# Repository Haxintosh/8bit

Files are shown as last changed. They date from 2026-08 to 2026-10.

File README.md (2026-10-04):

# 8bit
8-bit SAP-3 inspired architecture using 74xx series logic chips.

## Files
KiCad design files can be found under `schematic/`, clone and open `8bit.kicad_pro`.  
Schematic PDF is under `schematic/pdf/`.  
Simulation files for Digital can be found under `simulation/`.  
Open the `main_manual.dig` in Digital to view the simulation.  
Some of the hex files to program EEPROMs are under `simulation/hex/`.  

## Features
- 8 bit wide data bus
- 16 bit wide address bus
- 8 bit A/B/C/D/E/H/L/temporary registers
- BC, DE, HL can pair up to become a 16 bit wide register
- 32k RAM
- Memory-Mapped IO
- 16 bit stack pointer, memory address register, program counter
- 8080-like instruction set
- CompactFlash read/write
- LCD output

## Demo
1.  (Video) A simplified SAP-1 version running fibonacci sequence code.
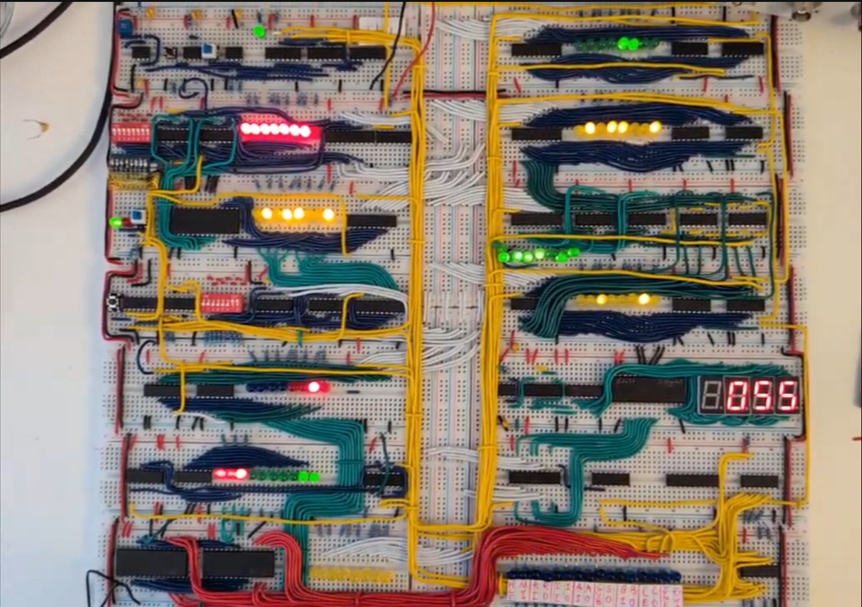
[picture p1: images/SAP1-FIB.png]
SAP-1 version running fibonacci sequence code (https://drive.google.com/file/d/1dBzOrb9bEsT9MGzf2OnXLOOiJT2EtECz/view?usp=sharing)


2. SAP-3 in simulation
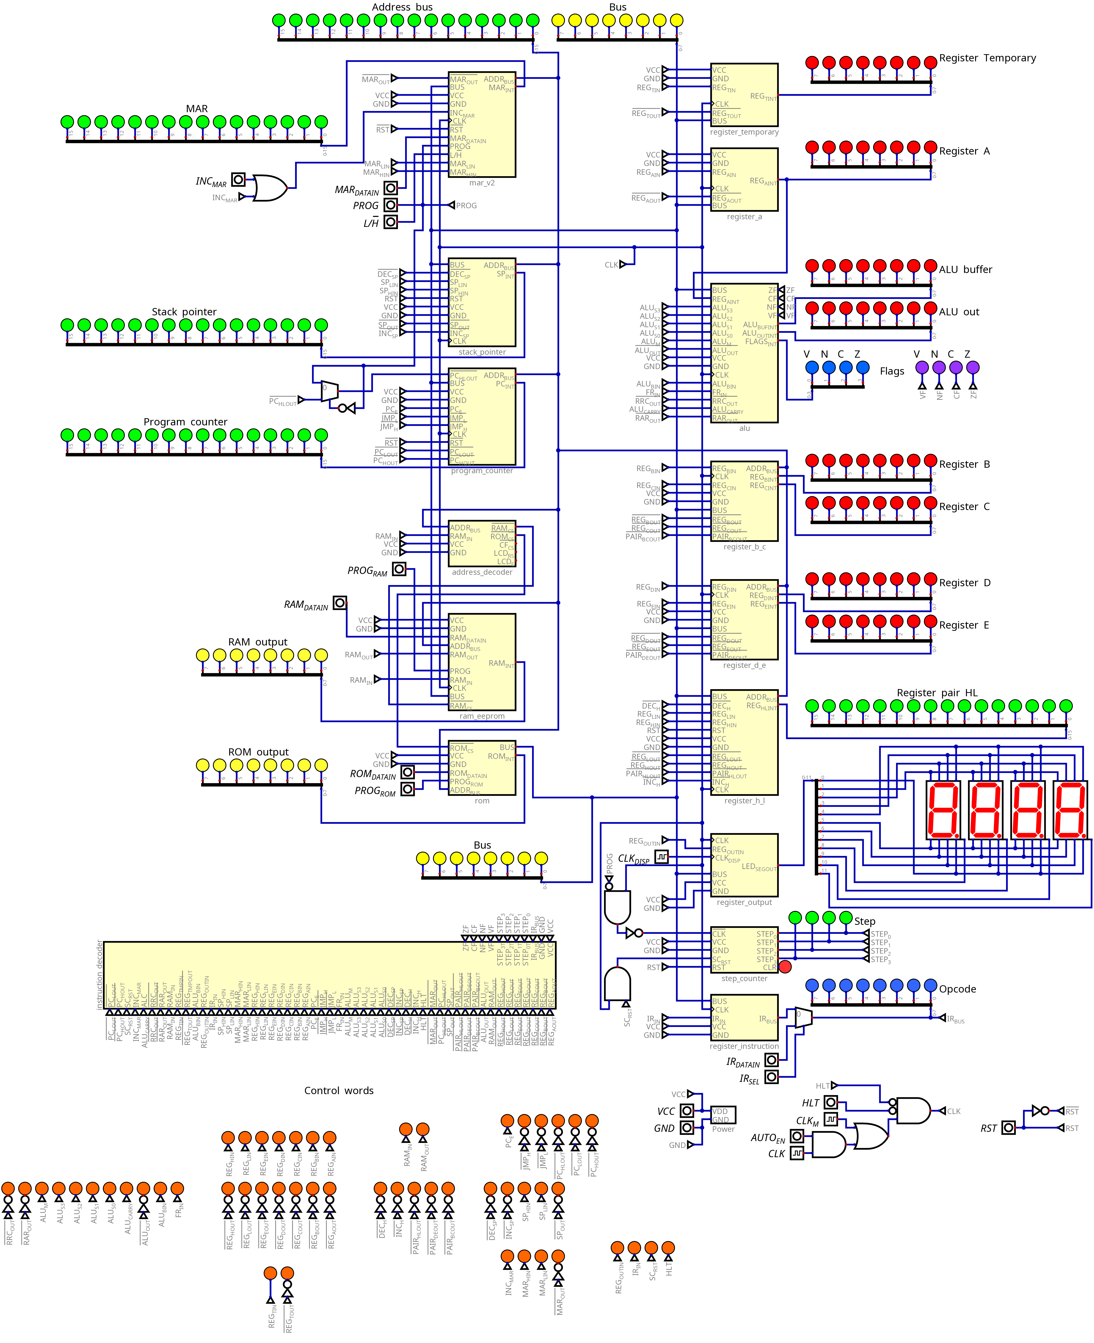
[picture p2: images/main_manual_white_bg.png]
SAP-3 digital simulation


3. (Video) SAP-3 running fibonacci code
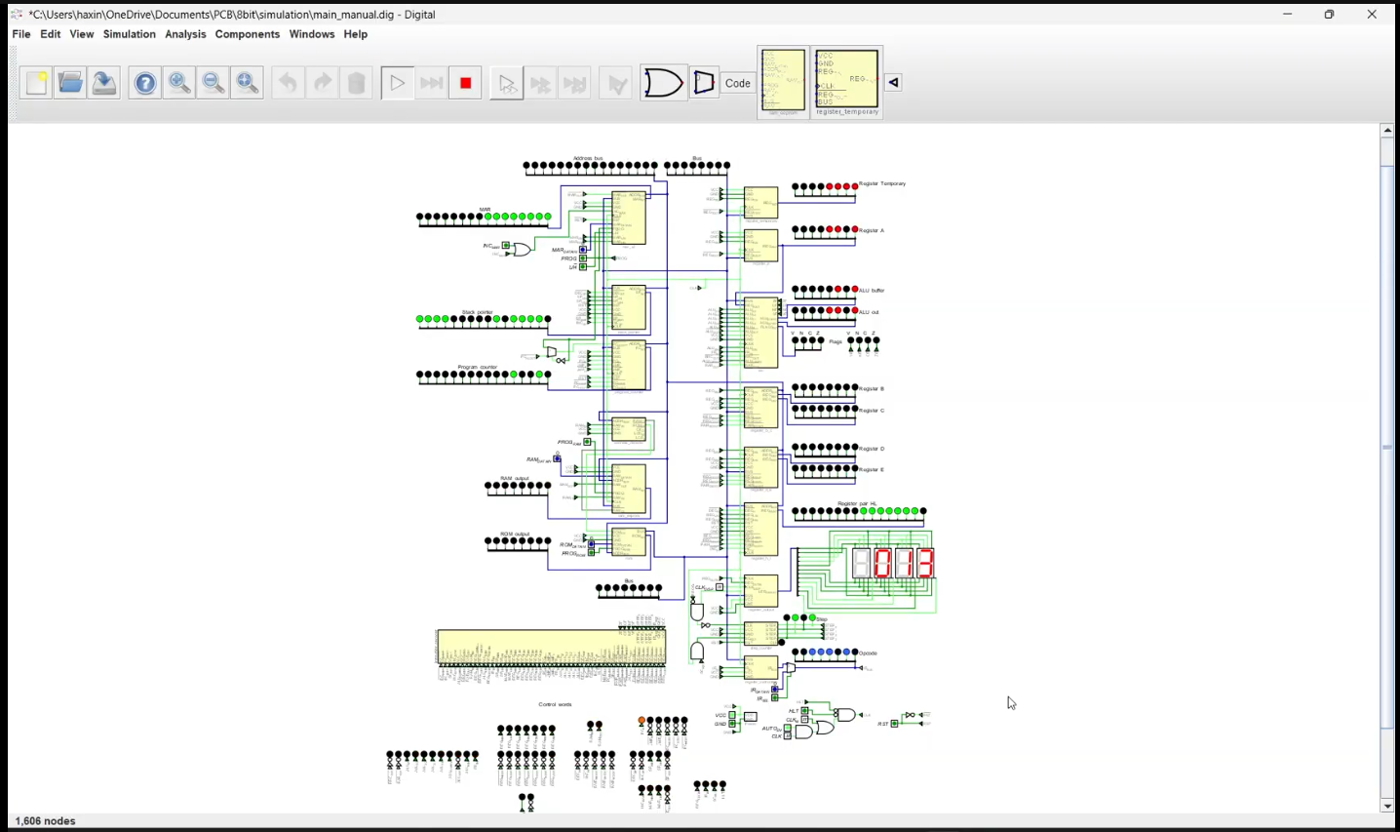
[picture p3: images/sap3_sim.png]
SAP-3 running fibonacci sequence code (https://drive.google.com/file/d/1ePPz25QHvrzXUbd5AwPUnTJGdm06tiAX/view?usp=sharing)


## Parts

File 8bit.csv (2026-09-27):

Reference | Qty | Value | DNP | Exclude from BOM | Exclude from Board | Footprint | Datasheet
C1,C2,C3,C5 | 4 | 0.01uF
C4 | 1 | 0.1uF
D17,D18,D19,D20,D21,D22,D23,D24,D25,D26,D27,D28,D29,D30,D31,D32,D33,D34,D35,D36,D37,D38,D39,D40,D41,D42,D43,D44,D45,D46,D47,D48,D49,D50,D51,D52,D53,D54,D55,D56,D57,D58,D59,D60,D61,D62,D63,D64,D65,D66,D67,D68,D69,D70,D71,D72,D73,D74,D75,D76,D77,D78,D79,D80,D81,D82,D83,D84,D85,D86,D87,D88,D89,D90,D91,D92,D93,D94,D95,D96,D97,D98,D99,D100,D101,D102,D103,D104,D105,D106,D107,D108,D109,D110,D111,D112,D113,D114,D115,D116,D117,D118,D119,D120,D121,D122,D123,D124,D125,D126,D127,D128,D129,D130,D131,D132,D133,D134,D135,D136,D137,D138,D139,D140,D141,D142,D143,D144,D145,D146,D147,D148,D149,D150,D151,D152,D153,D154,D155,D156,D157,D158,D159,D160,D161,D162,D163,D164,D165,D166,D167,D168,D169,D170,D171,D172,D173,D174,D175,D176,D177,D178,D179,D180,D181,D182,D183,D184,D185,D186,D187,D188,D189,D190,D191,D192,D193,D194,D195,D196,D197 | 181 | LED |  |  |  | LED_SMD:LED_0805_2012Metric
DS1 | 1 | WC1602A |  |  |  | Display:WC1602A | http://www.wincomlcd.com/pdf/WC1602A-SFYLYHTC06.pdf
J1 | 1 | CF |  |  |  | easyeda2kicad:CONN-SMD_HYCW01-CF50-395B
J2 | 1 | EXTR
JP1 | 1 | Master
R17,R18,R19,R20,R21,R22,R23,R24,R25,R26,R27,R28,R29,R30,R31,R32,R33,R34,R35,R36,R37,R38,R39,R40,R41,R42,R43,R44,R45,R46,R47,R48,R49,R50,R51,R52,R53,R54,R55,R56,R57,R58,R59,R60,R61,R62,R63,R64,R65,R66,R67,R68,R70,R72,R74,R76,R78,R80,R82,R84,R86,R88,R90,R92,R94,R96,R98,R100,R101,R102,R103,R104,R105,R106,R107,R108,R109,R110,R111,R112,R113,R114,R115,R116,R117,R118,R119,R120,R121,R122,R123,R124,R125,R126,R127,R128,R129,R130,R131,R132,R133,R134,R135,R136,R137,R138,R139,R140,R145,R146,R147,R148,R149,R150,R151,R152,R153,R154,R155,R156,R157,R158,R159,R160,R161,R162,R163,R164,R165,R166,R167,R168,R169,R170,R171,R172,R173,R174,R175,R176,R177,R178,R179,R180,R181,R182,R183,R184,R185,R186,R187,R188,R189,R190,R191,R192,R193,R194,R195,R196,R201,R204,R205,R206,R209,R210,R211,R212,R213,R214,R215,R216,R217,R218,R219,R220,R221,R222,R223,R224,R225 | 181 | 470 |  |  |  | Resistor_SMD:R_0805_2012Metric
R69,R71,R73,R75,R77,R79,R81,R83,R85,R87,R89,R91,R93,R95,R97,R99,R232,R233,R234,R235,R236,R237,R238,R239,R240,R241,R242,R243,R244,R245,R246,R247 | 32 | 1k |  |  |  | Resistor_SMD:R_0805_2012Metric
R141,R142 | 2 | R
R143 | 1 | 1M
R144,R207,R208 | 3 | 1k
R197,R198,R199,R200,R202 | 5 | 0 |  |  |  | Resistor_SMD:R_0805_2012Metric
R203 | 1 | 4.7k |  |  |  | Resistor_SMD:R_0805_2012Metric
RV1 | 1 | 10k
SW1 | 1 | RST
SW2 | 1 | SW_Push
SW3 | 1 | SW_SPDT
SW4,SW5 | 2 | SW_DIP_x08
U1,U81 | 2 | 74LS04 |  |  |  |  | http://www.ti.com/lit/gpn/sn74LS04
U2,U3,U82,U95 | 4 | 74LS08 |  |  |  |  | http://www.ti.com/lit/gpn/sn74LS08
U3,U83 | 2 | 74LS32 |  |  |  |  | http://www.ti.com/lit/gpn/sn74LS32
U4 | 1 | 74LS02 |  |  |  |  | http://www.ti.com/lit/gpn/sn74ls02
U5,U6,U7,U8,U61,U84,U85,U86,U87 | 9 | 74LS161 |  |  |  | Package_DIP:DIP-16_W7.62mm_Socket | http://www.ti.com/lit/gpn/sn74LS161
U9,U10,U15,U16,U20,U21,U23,U25,U30,U31,U37,U39,U40,U41,U44,U45,U46,U47,U50,U51,U52,U53,U70,U88,U89,U93,U94 | 27 | 74LS245 |  |  |  | Package_DIP:DIP-20_W7.62mm_Socket | http://www.ti.com/lit/gpn/sn74LS245
U11,U12,U13,U14,U26,U27,U48,U49 | 8 | 74LS193 |  |  |  | Package_DIP:DIP-16_W7.62mm_Socket | http://www.ti.com/lit/ds/symlink/sn74ls193.pdf
U17 | 1 | 74LS138 |  |  |  | Package_DIP:DIP-16_W7.62mm_Socket | http://www.ti.com/lit/gpn/sn74LS138
U18 | 1 | 74LS20 |  |  |  | Package_DIP:DIP-14_W7.62mm_Socket | http://www.ti.com/lit/gpn/sn74LS20
U19 | 1 | HM62256BLP |  |  |  | Package_DIP:DIP-28_W15.24mm_Socket | https://web.mit.edu/6.115/www/document/62256.pdf
U22 | 1 | KM28C64A |  |  |  | Package_DIP:DIP-28_W15.24mm_Socket | https://tvsat.com.pl/PDF/K/km28c64_sam.pdf
U24,U32,U36,U38,U42,U43,U54,U55,U67 | 9 | 74LS573 |  |  |  | Package_DIP:DIP-20_W7.62mm_Socket | https://assets.nexperia.com/documents/data-sheet/74HC_HCT573.pdf
U28,U29 | 2 | 74LS181 |  |  |  | Package_DIP:DIP-24_W15.24mm_Socket | https://datasheets.chipdb.org/Fairchild/74F181PC.pdf
U33,U69,U71,U72,U73,U74,U75,U76 | 8 | 74LS08 |  |  |  | Package_DIP:DIP-14_W7.62mm_Socket | http://www.ti.com/lit/gpn/sn74LS08
U34,U62 | 2 | 74LS02 |  |  |  | Package_DIP:DIP-14_W7.62mm_Socket | http://www.ti.com/lit/gpn/sn74ls02
U35 | 1 | 74LS04 |  |  |  | Package_DIP:DIP-14_W7.62mm_Socket | http://www.ti.com/lit/gpn/sn74LS04
U56 | 1 | ATmega328-P |  |  |  | Package_DIP:DIP-28_W7.62mm | http://ww1.microchip.com/downloads/en/DeviceDoc/ATmega328_P%20AVR%20MCU%20with%20picoPower%20Technology%20Data%20Sheet%2040001984A.pdf
U57,U58,U59,U60 | 4 | D198K |  |  |  | Display_7Segment:D1X8K | https://ia800903.us.archive.org/24/items/CTKD1x8K/Cromatek%20D168K.pdf
U63,U64,U65,U66 | 4 | 27C512 |  |  |  | Package_DIP:DIP-28_W15.24mm | http://ww1.microchip.com/downloads/en/DeviceDoc/doc0015.pdf
U68 | 1 | 74LS00 |  |  |  | Package_DIP:DIP-14_W7.62mm_Socket | http://www.ti.com/lit/gpn/sn74ls00
U77 | 1 | 74LS86 |  |  |  | Package_DIP:DIP-14_W7.62mm_Socket | https://www.jameco.com/Jameco/Products/ProdDS/48098.pdf
U78,U79,U80 | 3 | NE555P |  |  |  | Package_DIP:DIP-8_W7.62mm | http://www.ti.com/lit/ds/symlink/ne555.pdf
U90,U91 | 2 | 74LS245 |  |  |  |  | http://www.ti.com/lit/gpn/sn74LS245
U92 | 1 | 74LS00 |  |  |  |  | http://www.ti.com/lit/gpn/sn74ls00
U96 | 1 | 74LS573 |  |  |  |  | https://assets.nexperia.com/documents/data-sheet/74HC_HCT573.pdf

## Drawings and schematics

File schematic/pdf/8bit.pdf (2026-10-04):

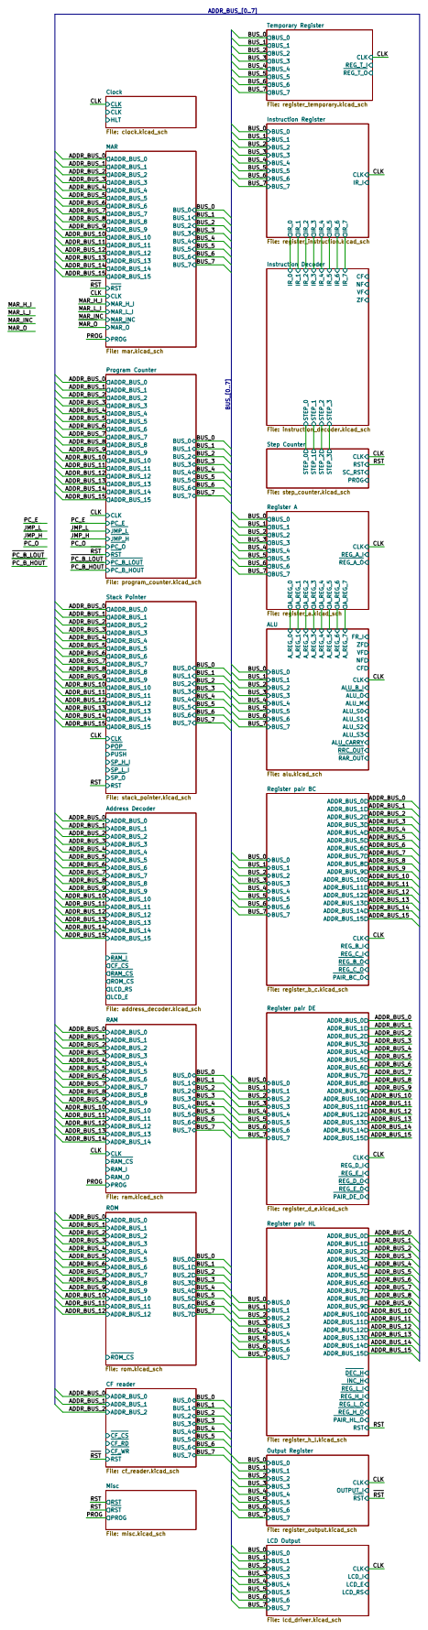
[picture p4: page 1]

Instruction Register File: register_instruction.kicad_sch CF NF STEP_0 STEP_1 STEP_2 STEP_3

RST CF reader File: cf_reader.kicad_sch

Size: A2 | Rev:
KiCad E.D.A. 10.0.6 | Id: 1/21

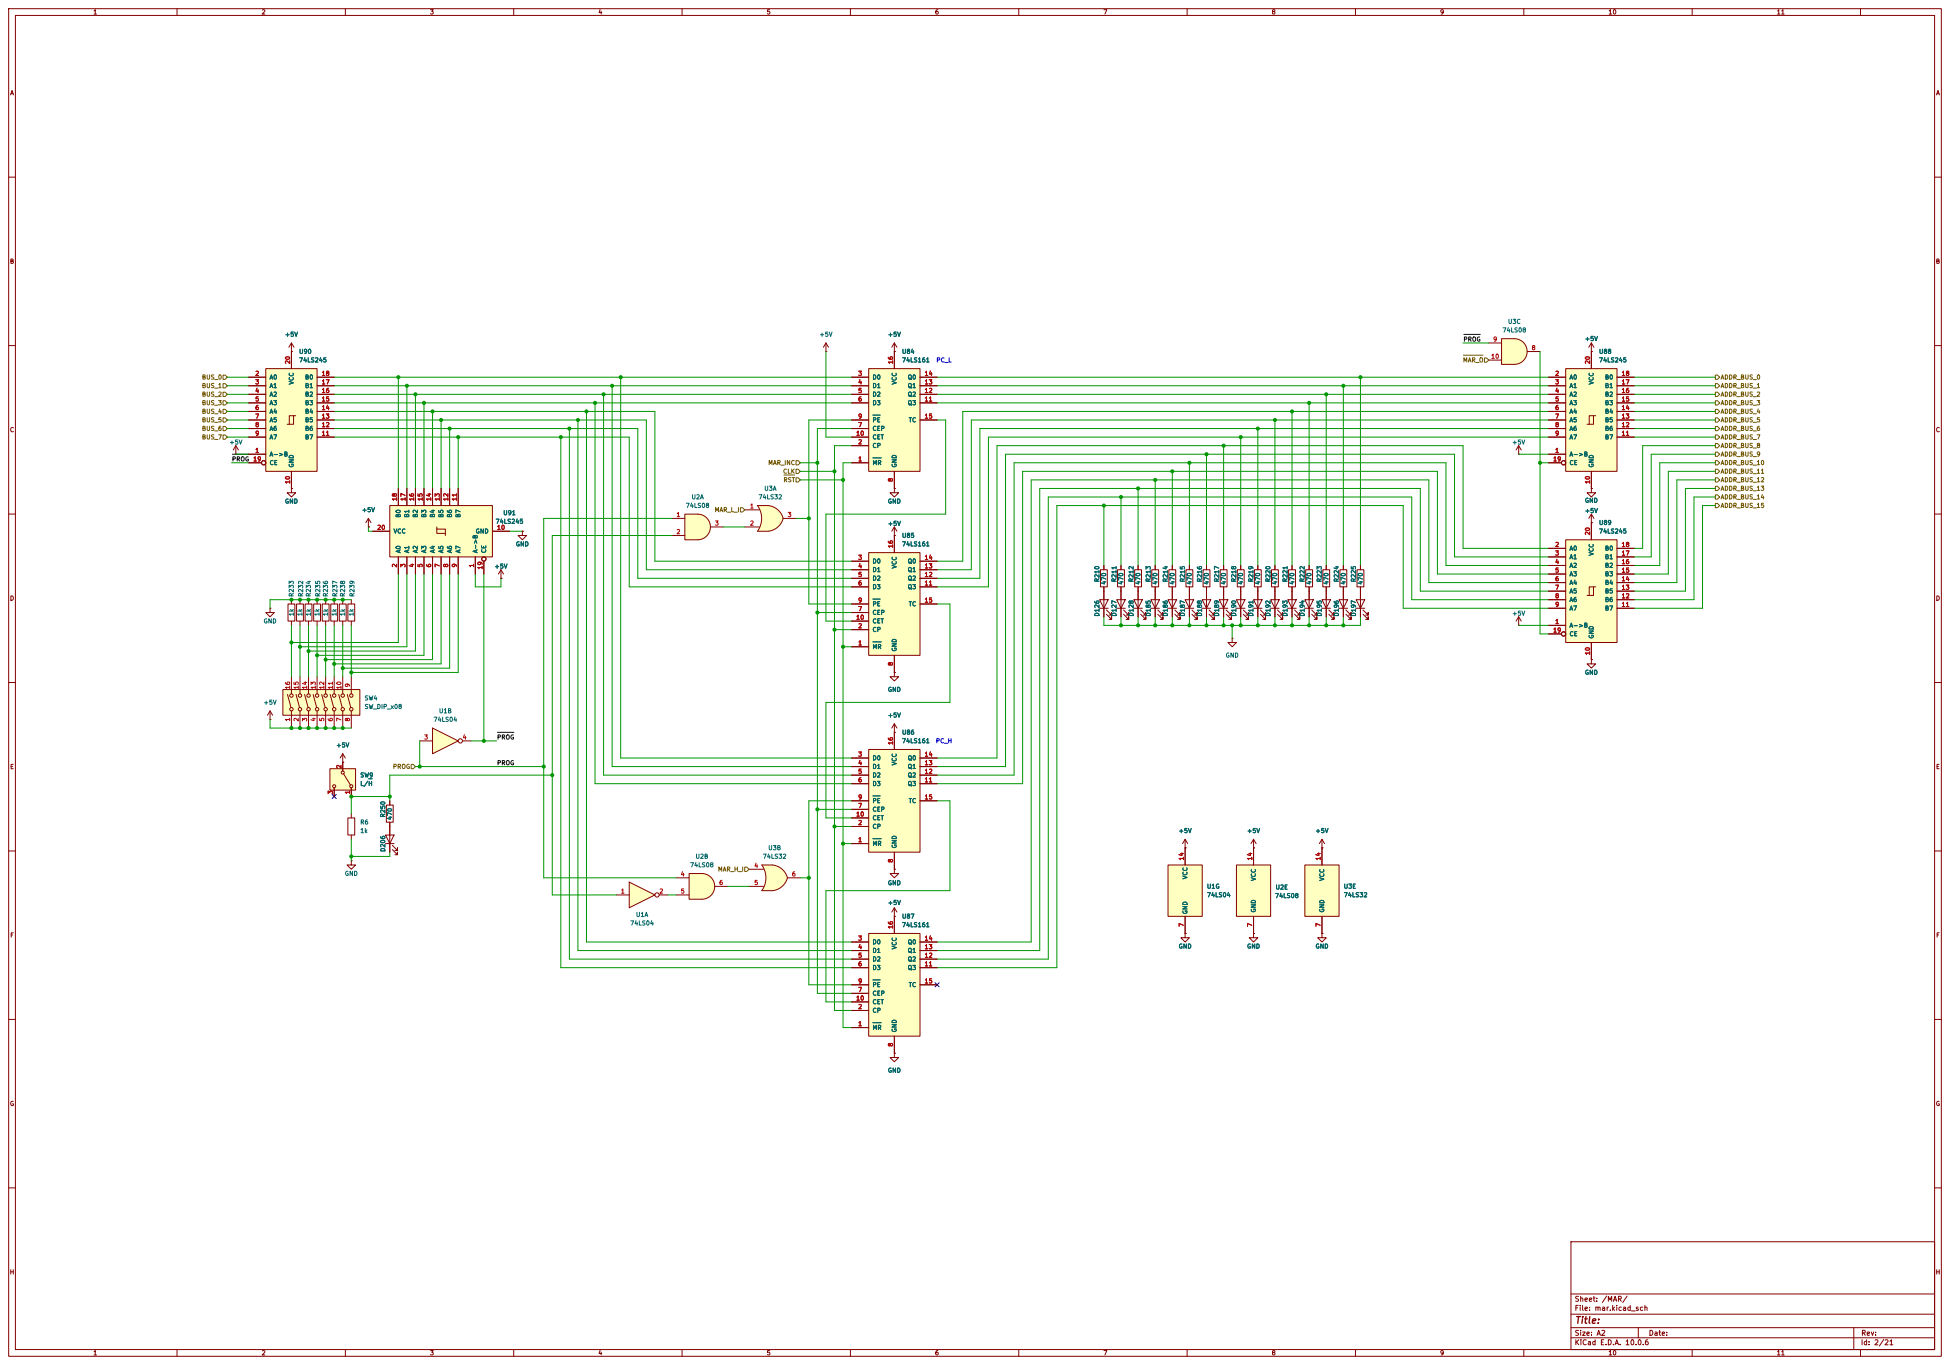
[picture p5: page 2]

5 5
6 6
7 7
8 8

74LS161 GND

A0 A0 A1 A1 A2 A2 A3 A3 A4 A4 A6 A6 A7 A7 A->B A->B | VCC 20 U89 | 18 CE 19

3 3 | 17 B0
4 4 | 16 B1
5 5 | 15 B2
6 6 | 14 B3
7 7 | 13 B4

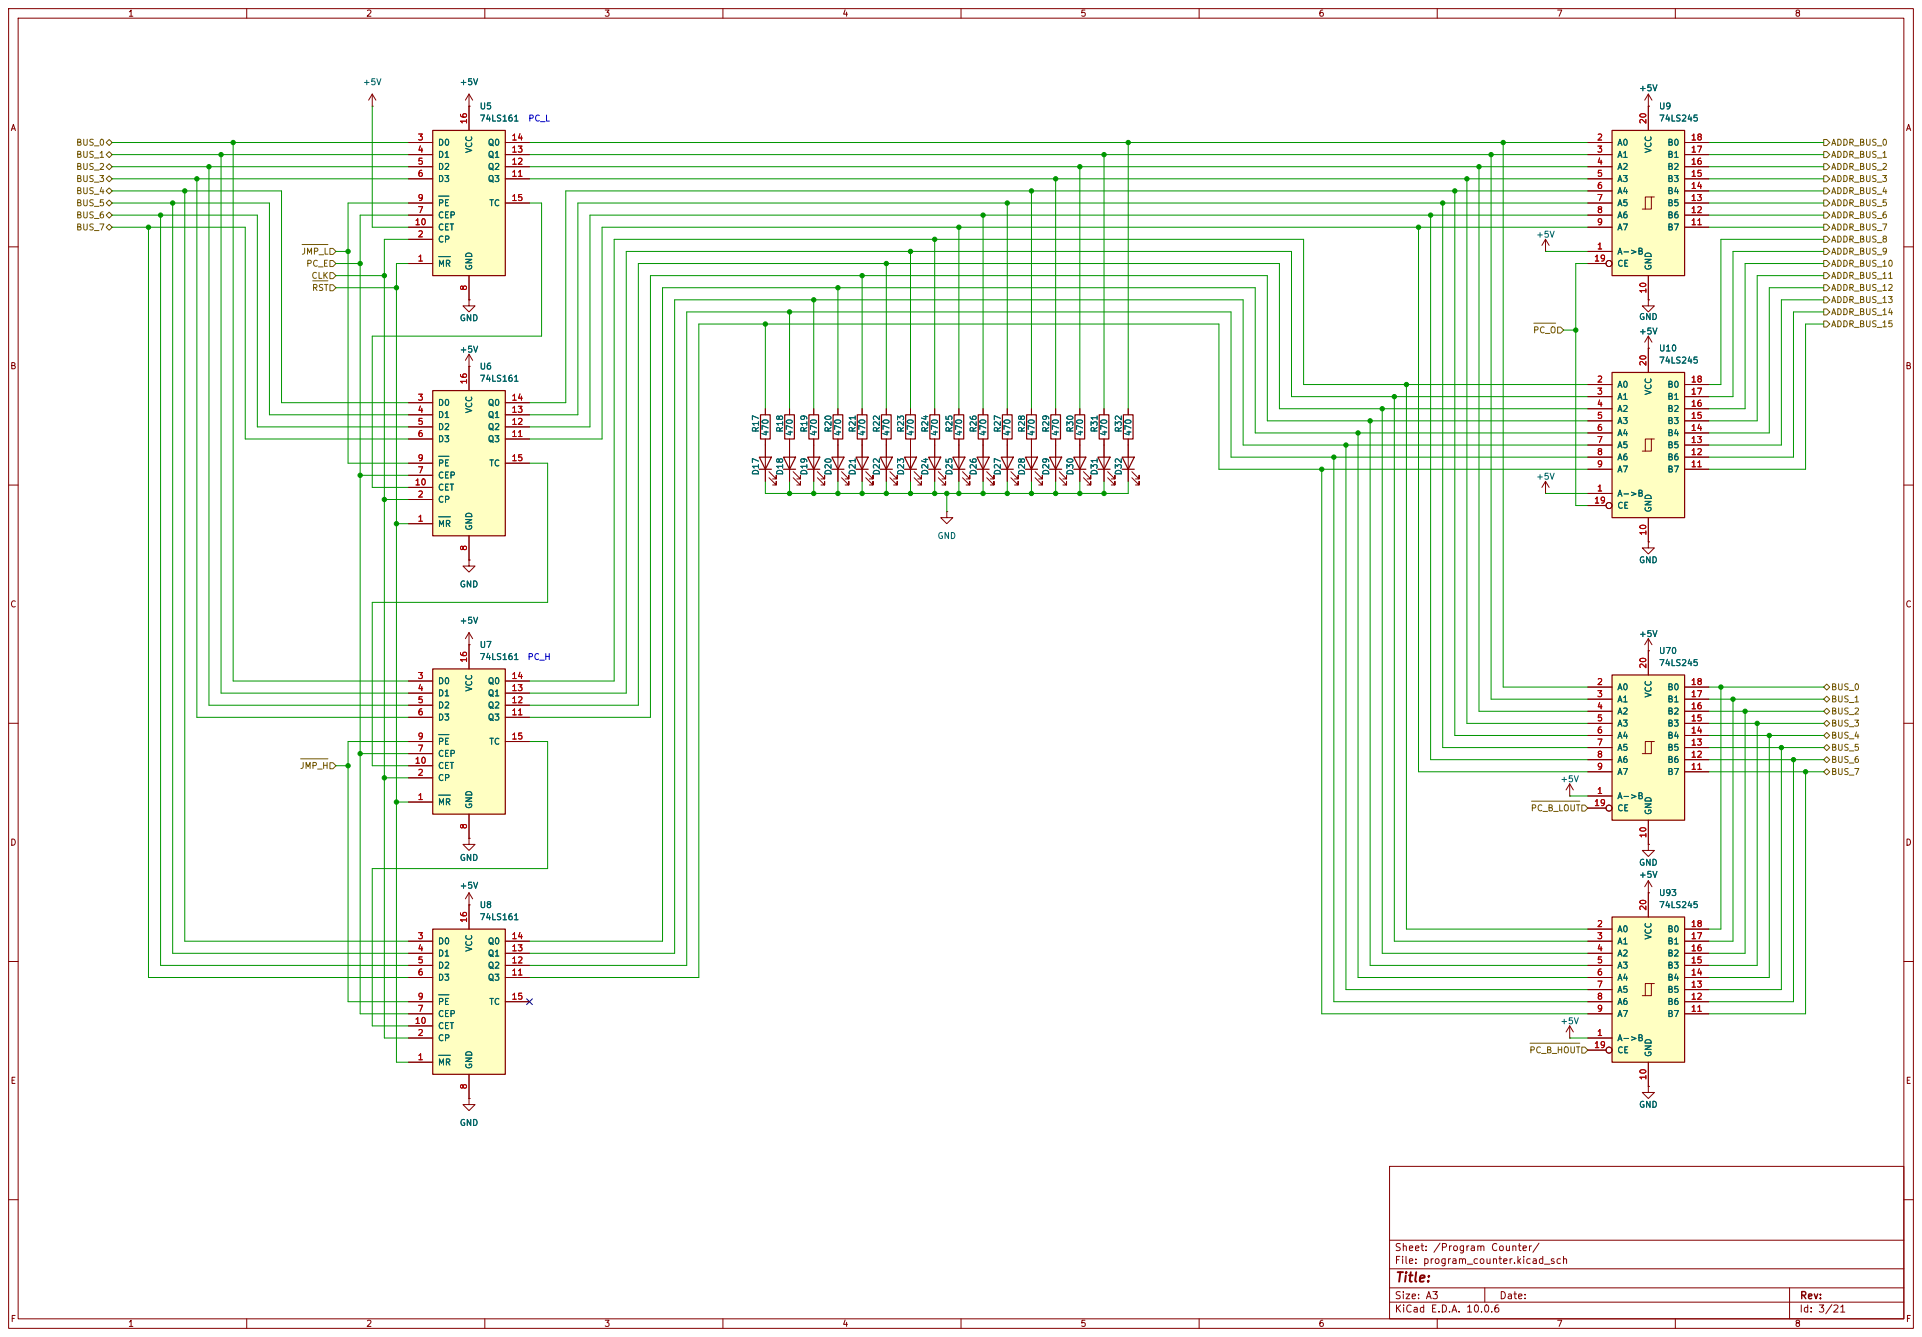
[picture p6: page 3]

A1 3
A2 4
A3 5
A4 6

A1 3 | 17 B0
A2 4 | 16 B1
A3 5 | 15 B2
A4 6 | 14 B3

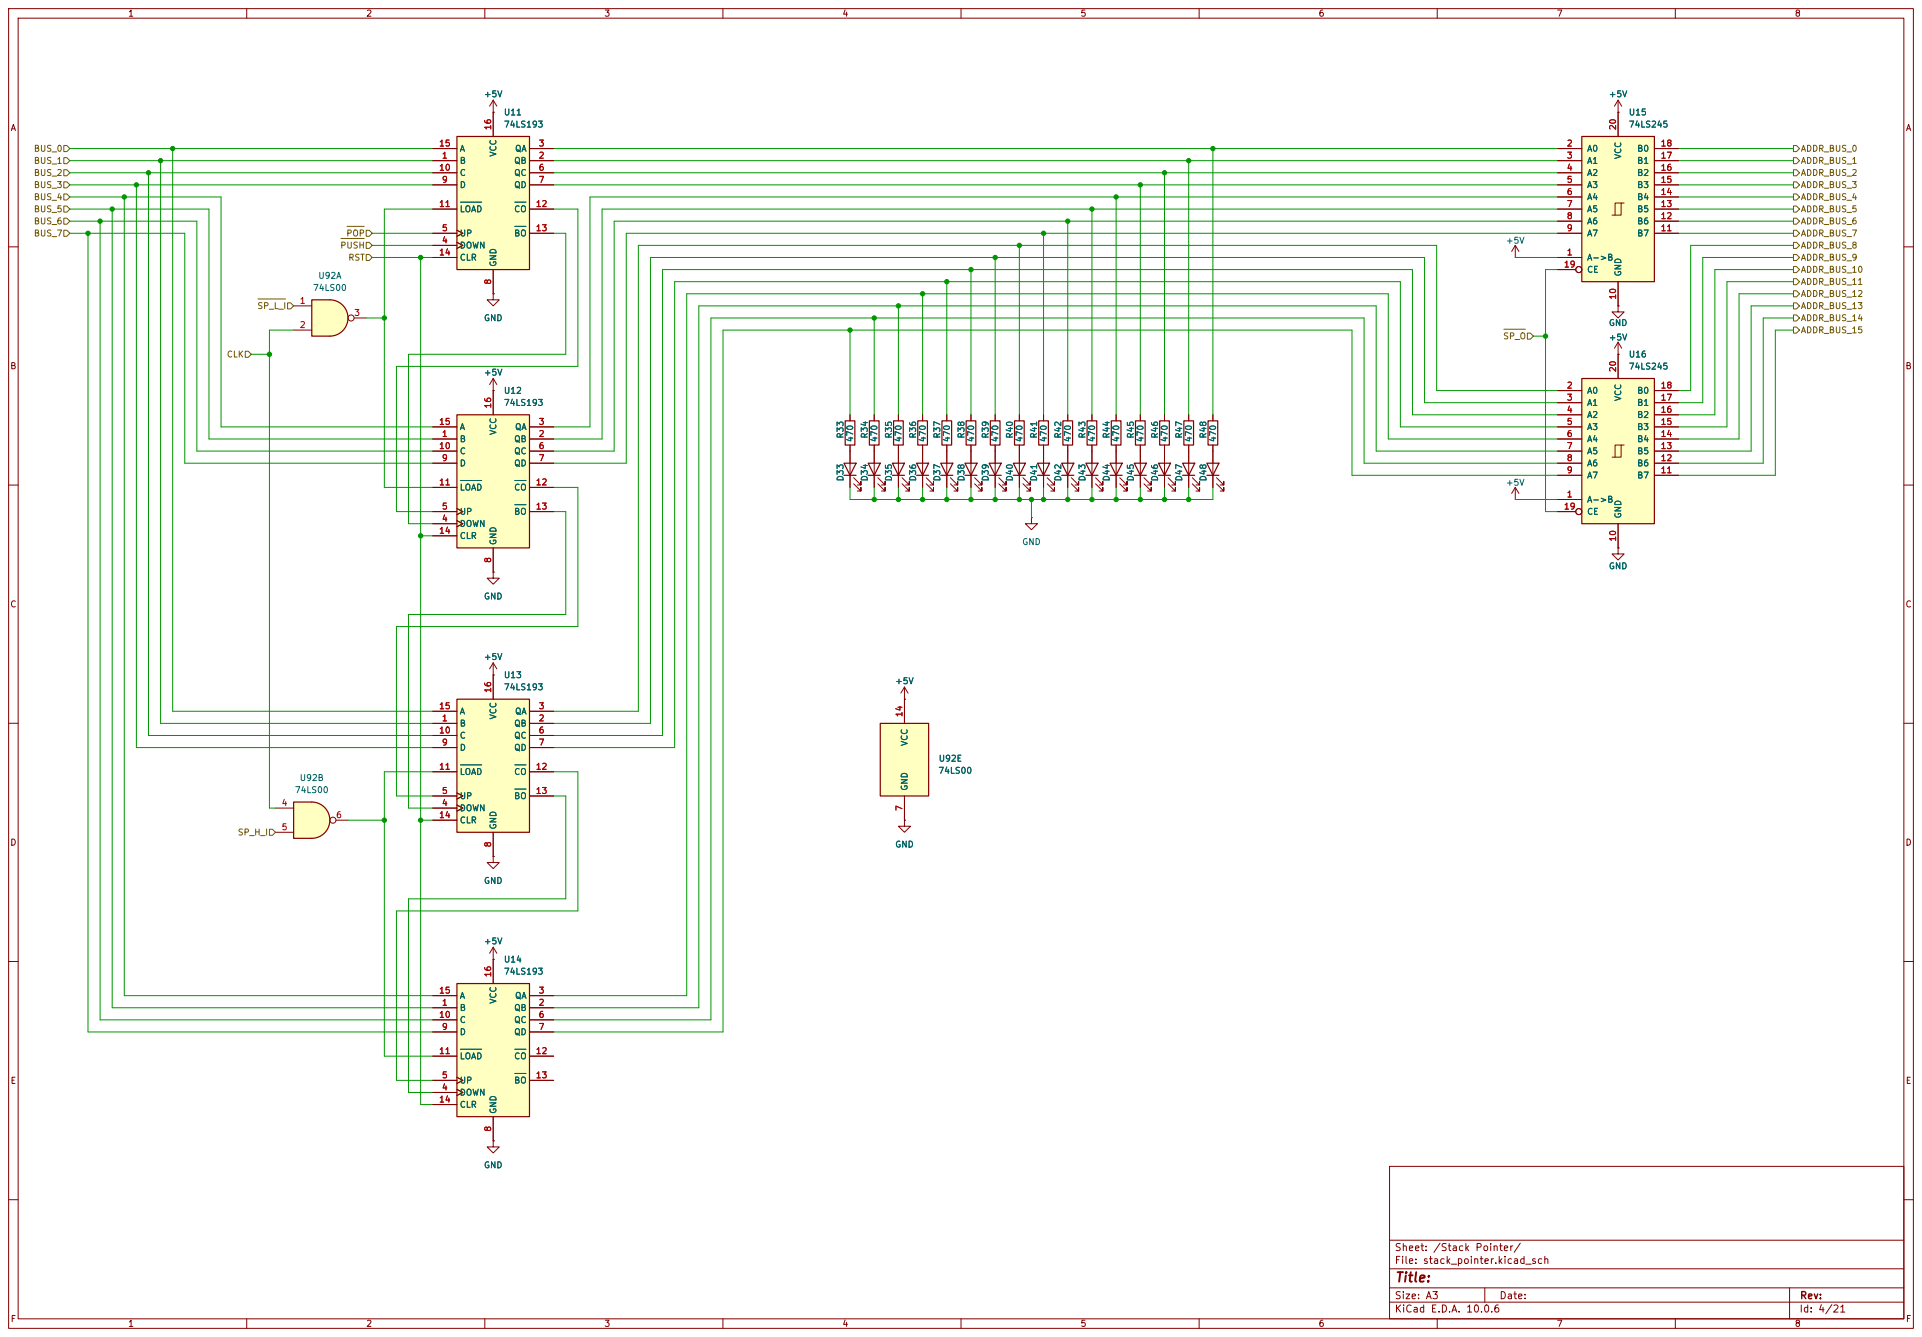
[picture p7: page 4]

A1 3 | 17 B0
A2 4 | 16 B1
A3 5 | 15 B2
A4 6 | 14 B3
A5 7 | 13 B4
A6 8 | 12 B5

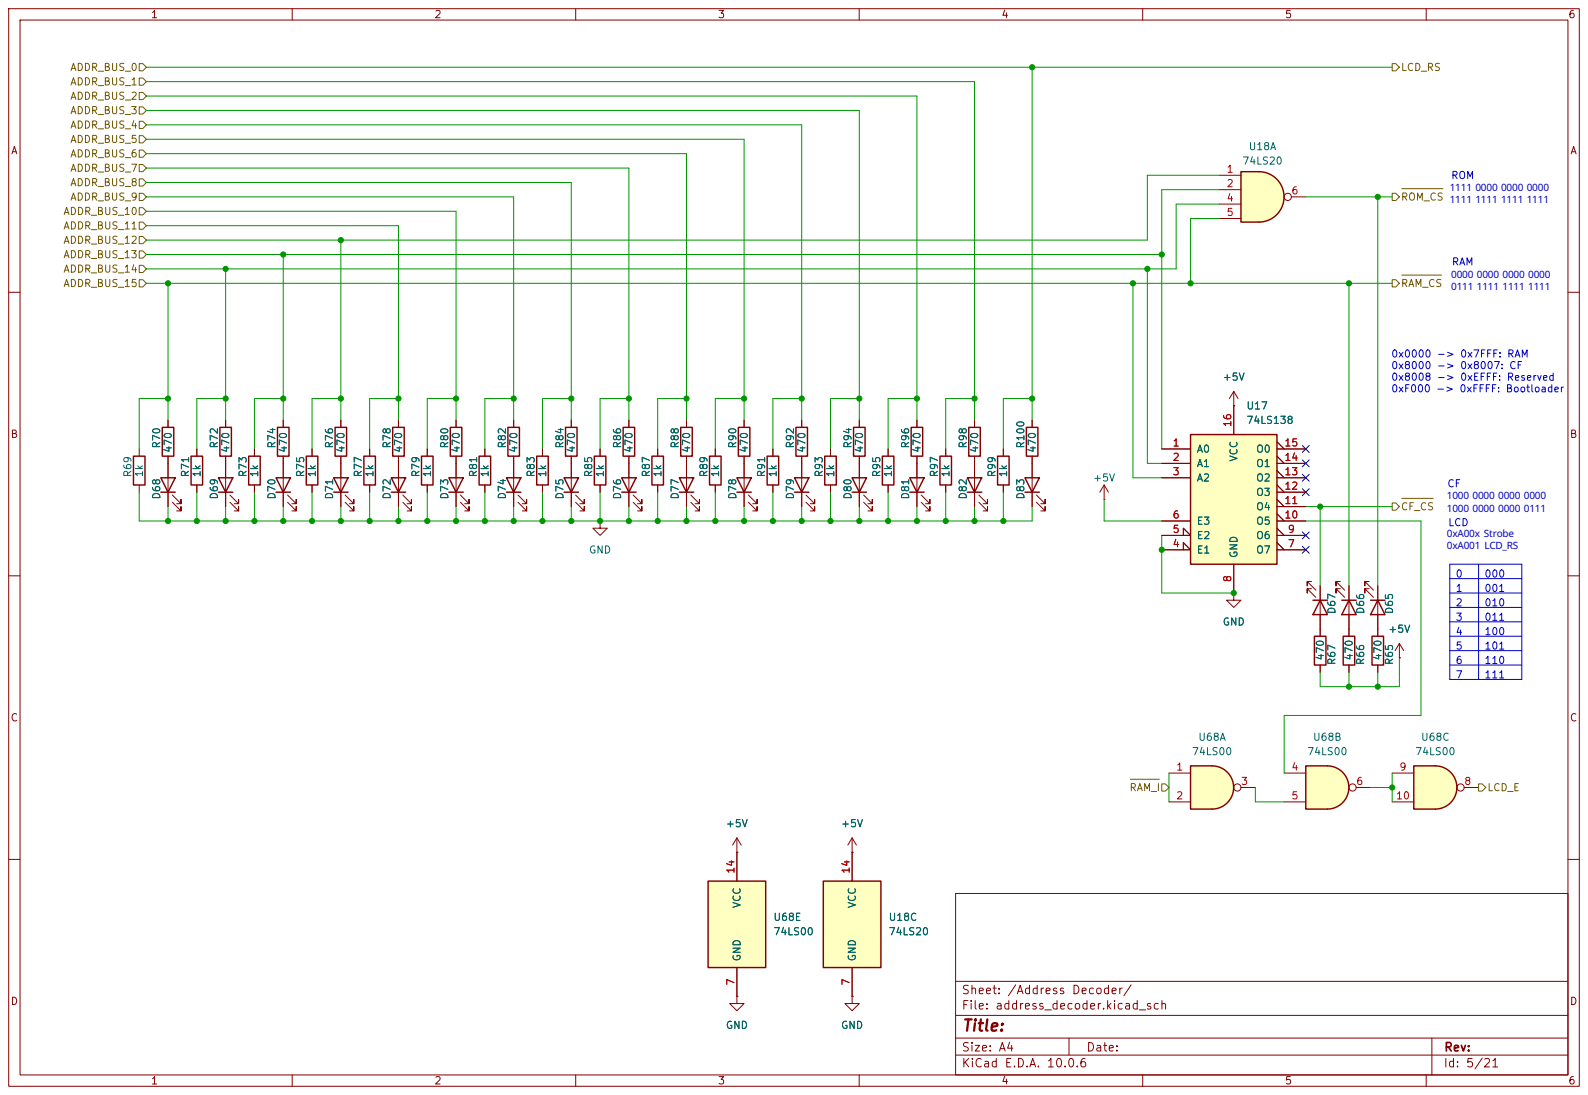
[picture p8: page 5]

7 VCC 14 GND GND +5V +5V D67 D66 D65 +5V R67 470 GND R65 470 R66 470 D68 D69 R70 470 D70 R74 470 R71 1kR73 1kR75 1k R72 470 R93 1k R98 470 R97 1kR99 1k D82 D83 R100 470 R95 1k D80 D81 R96 470 R94 470 R79 1k D72 R77 1k R78 470 D71 R76 470 R80 470 R82 470 D74 R83 1k D73 R81 1k D77 R87 1kR89 1k R88 470 D75 D76 R85 1k R86 470 R84 470 R90 470 D78 R92 470 R91 1k D79

0 | 000
1 | 001
2 | 010
3 | 011
4 | 100
5 | 101
6 | 110
7 | 111

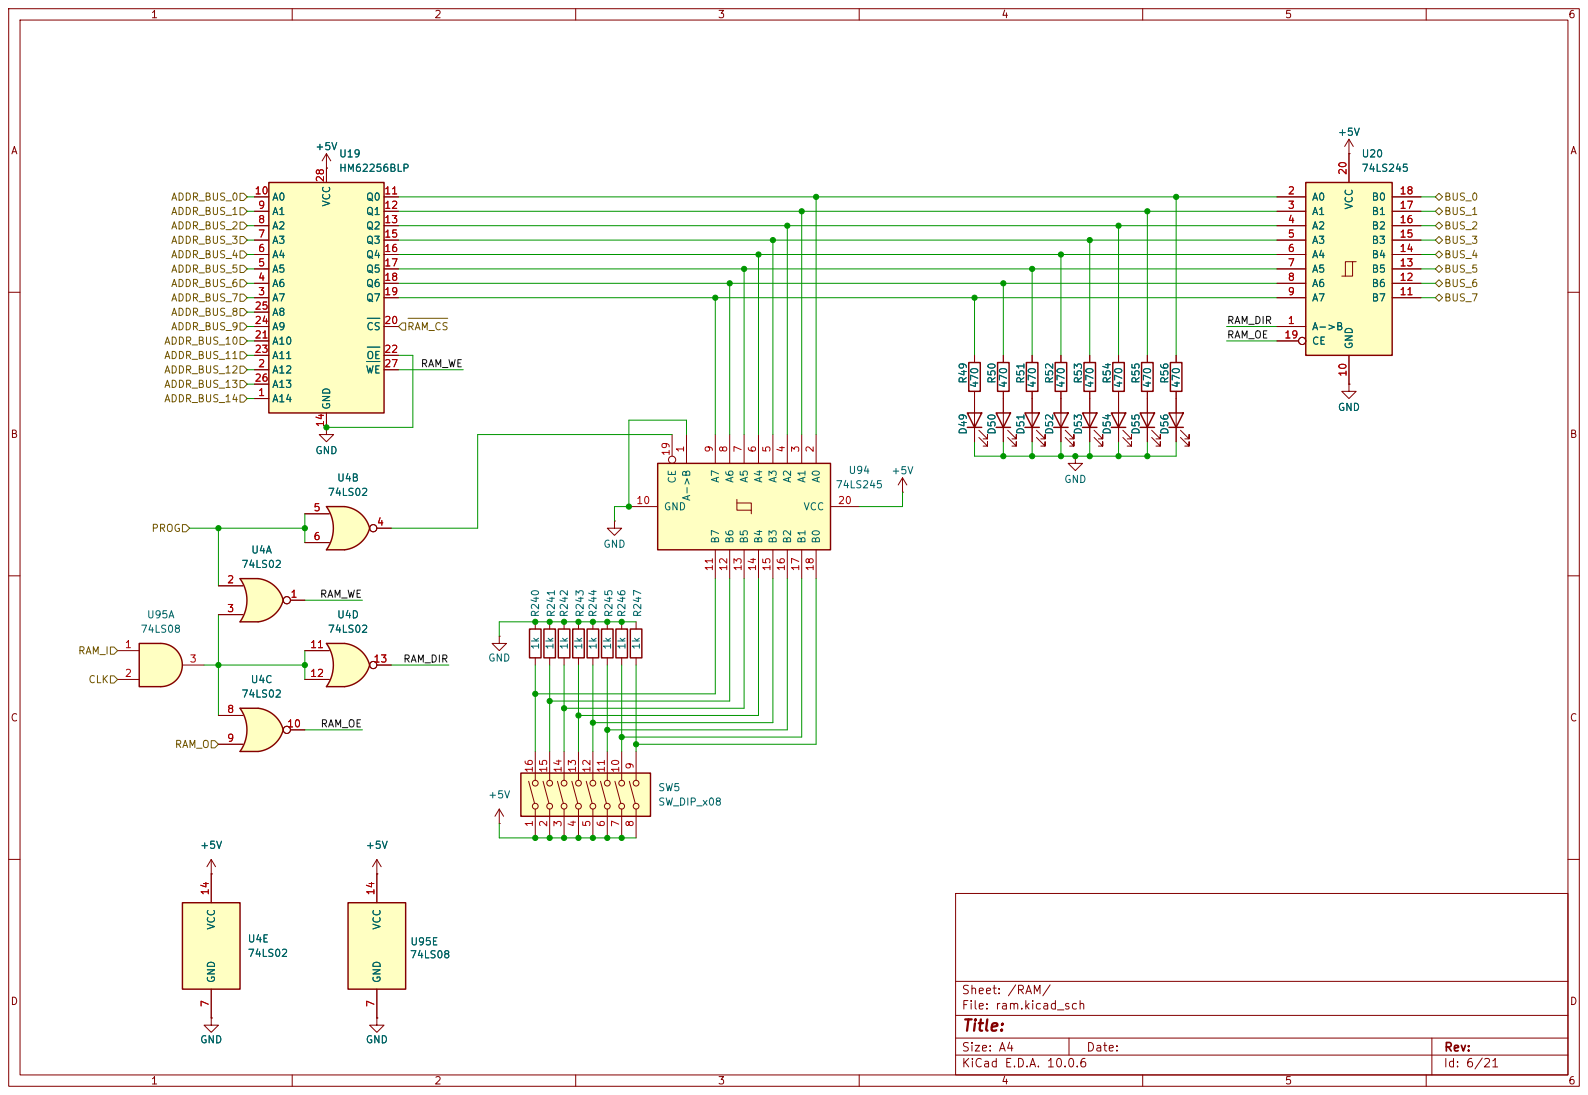
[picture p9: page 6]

A1 3
A2 4
A3 5
A4 6
A5 7
A6 8

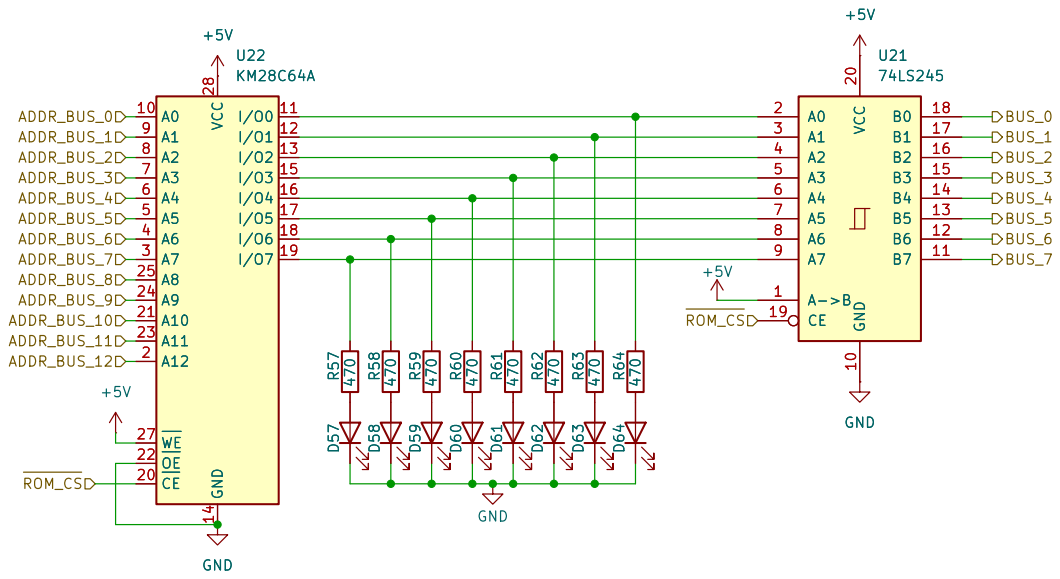
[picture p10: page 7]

A1 3
A2 4
A3 5
A4 6

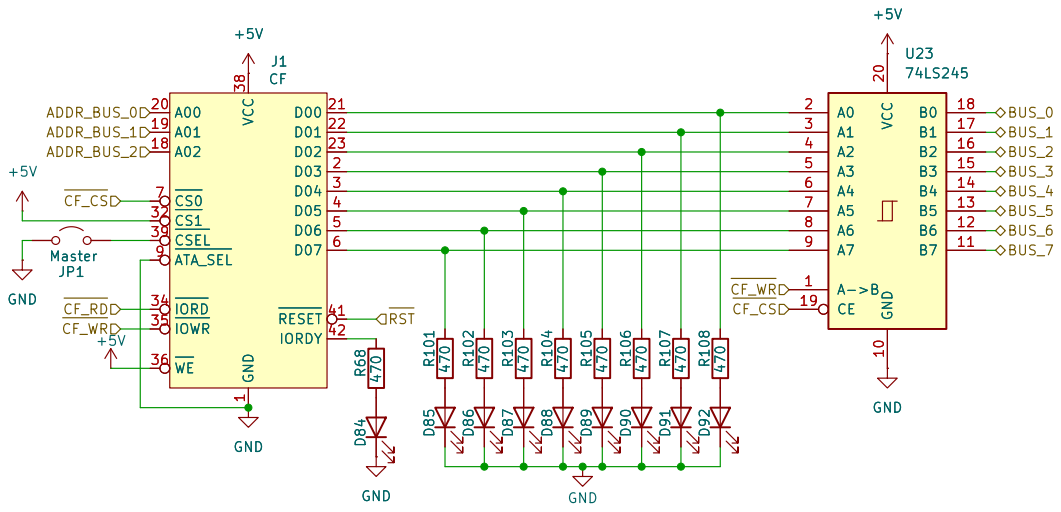
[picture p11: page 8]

A1 3
A2 4
A3 5
A4 6
A5 7
A6 8

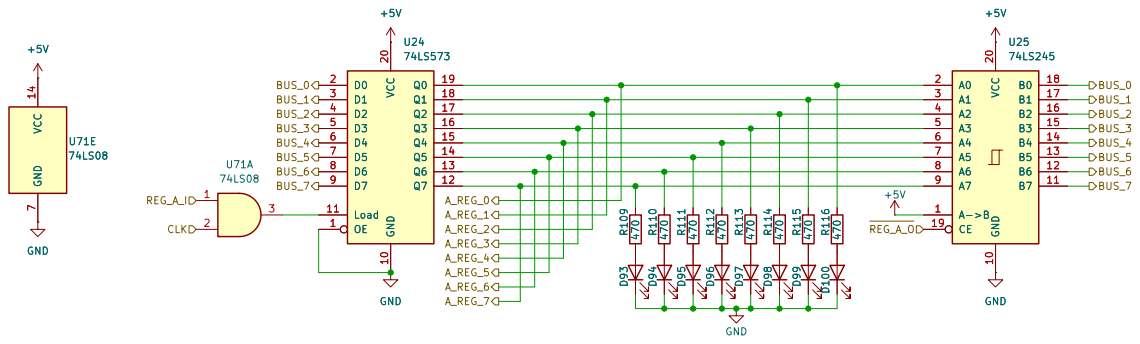
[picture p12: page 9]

A5 7
A6 8

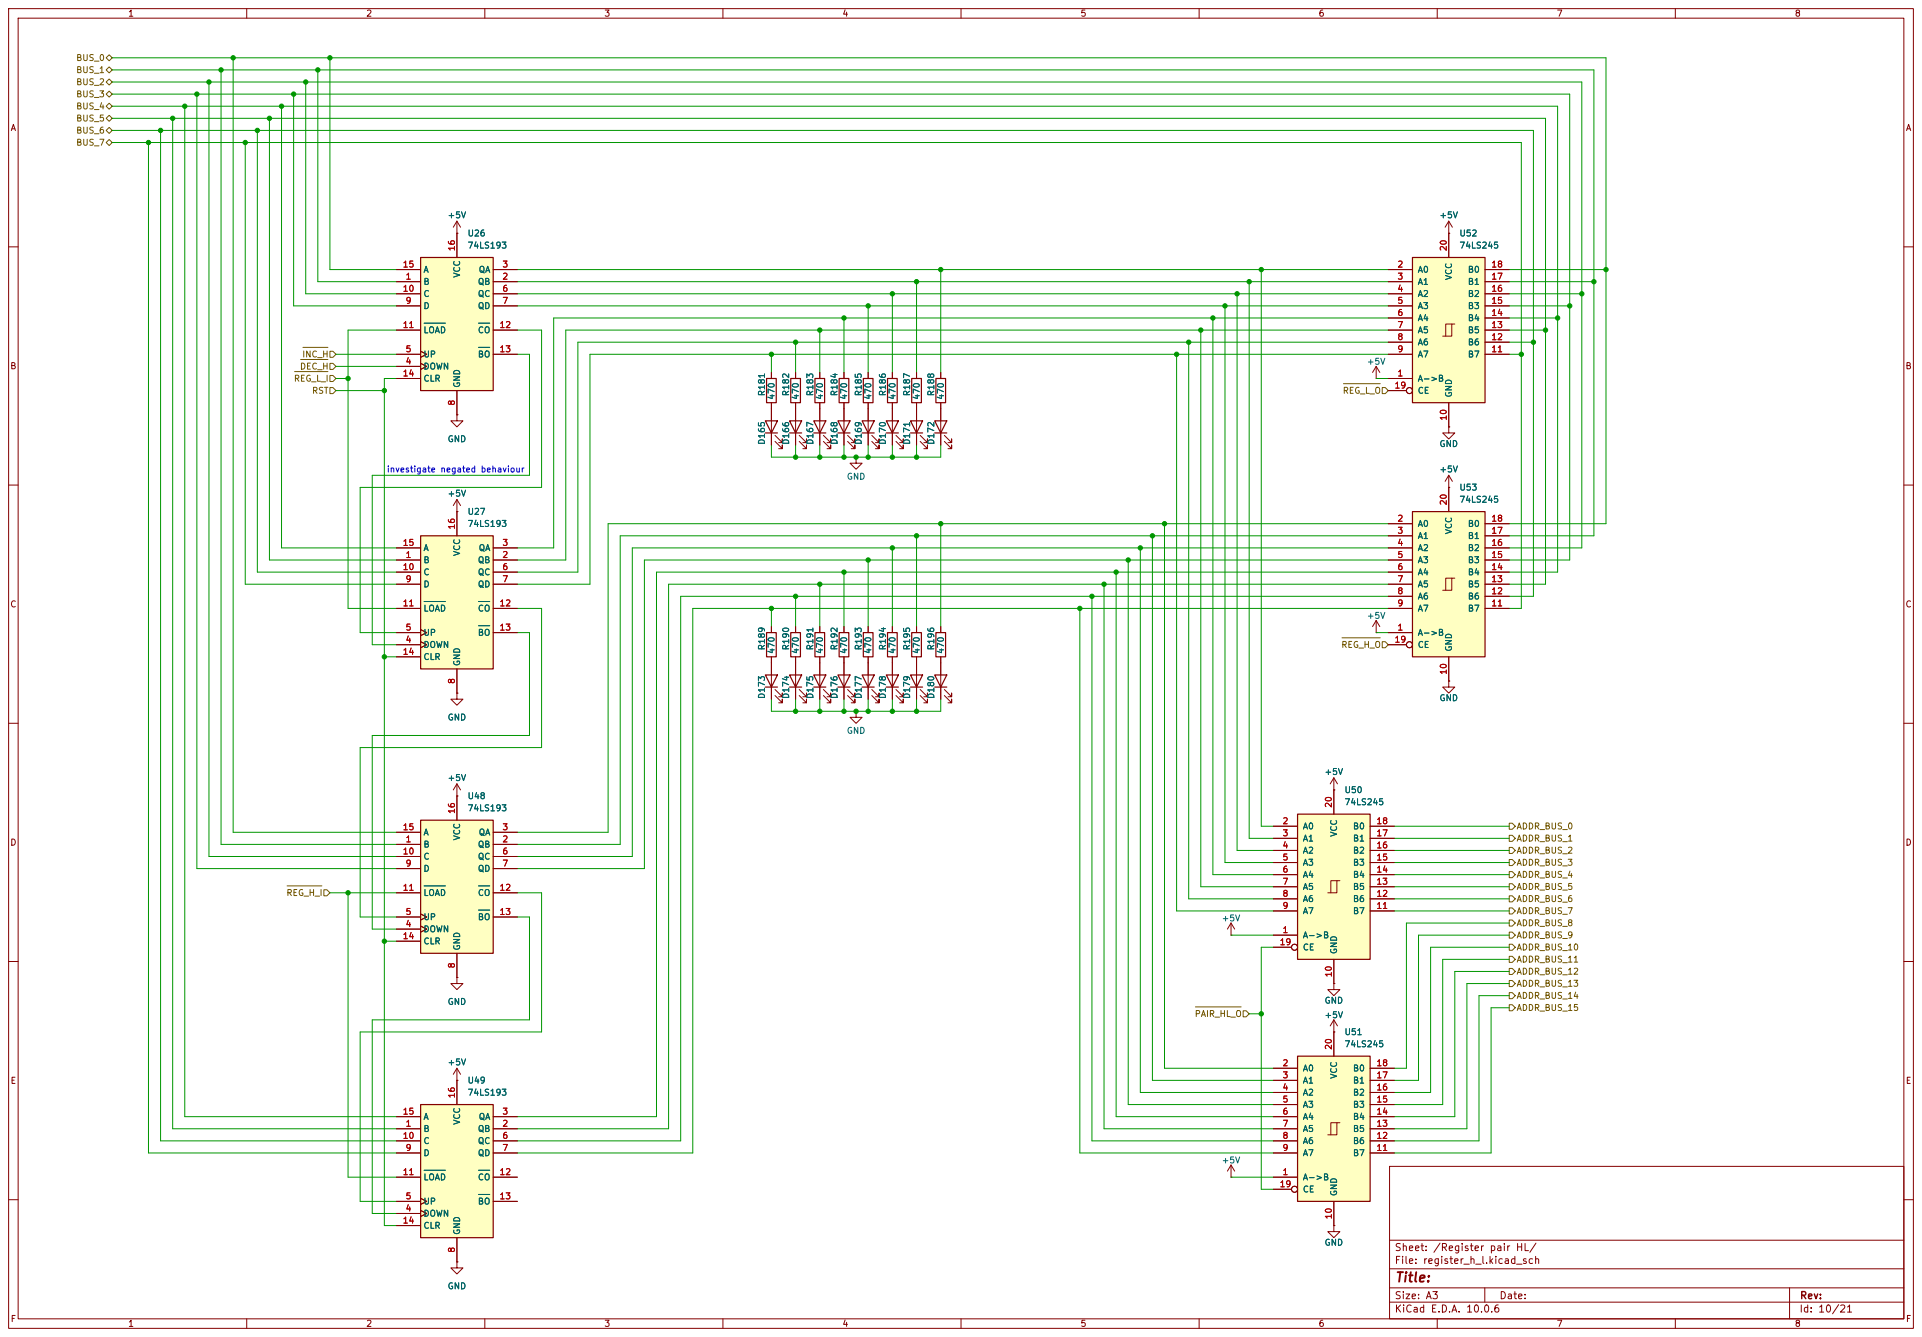
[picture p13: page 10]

A4 6
A5 7
A6 8

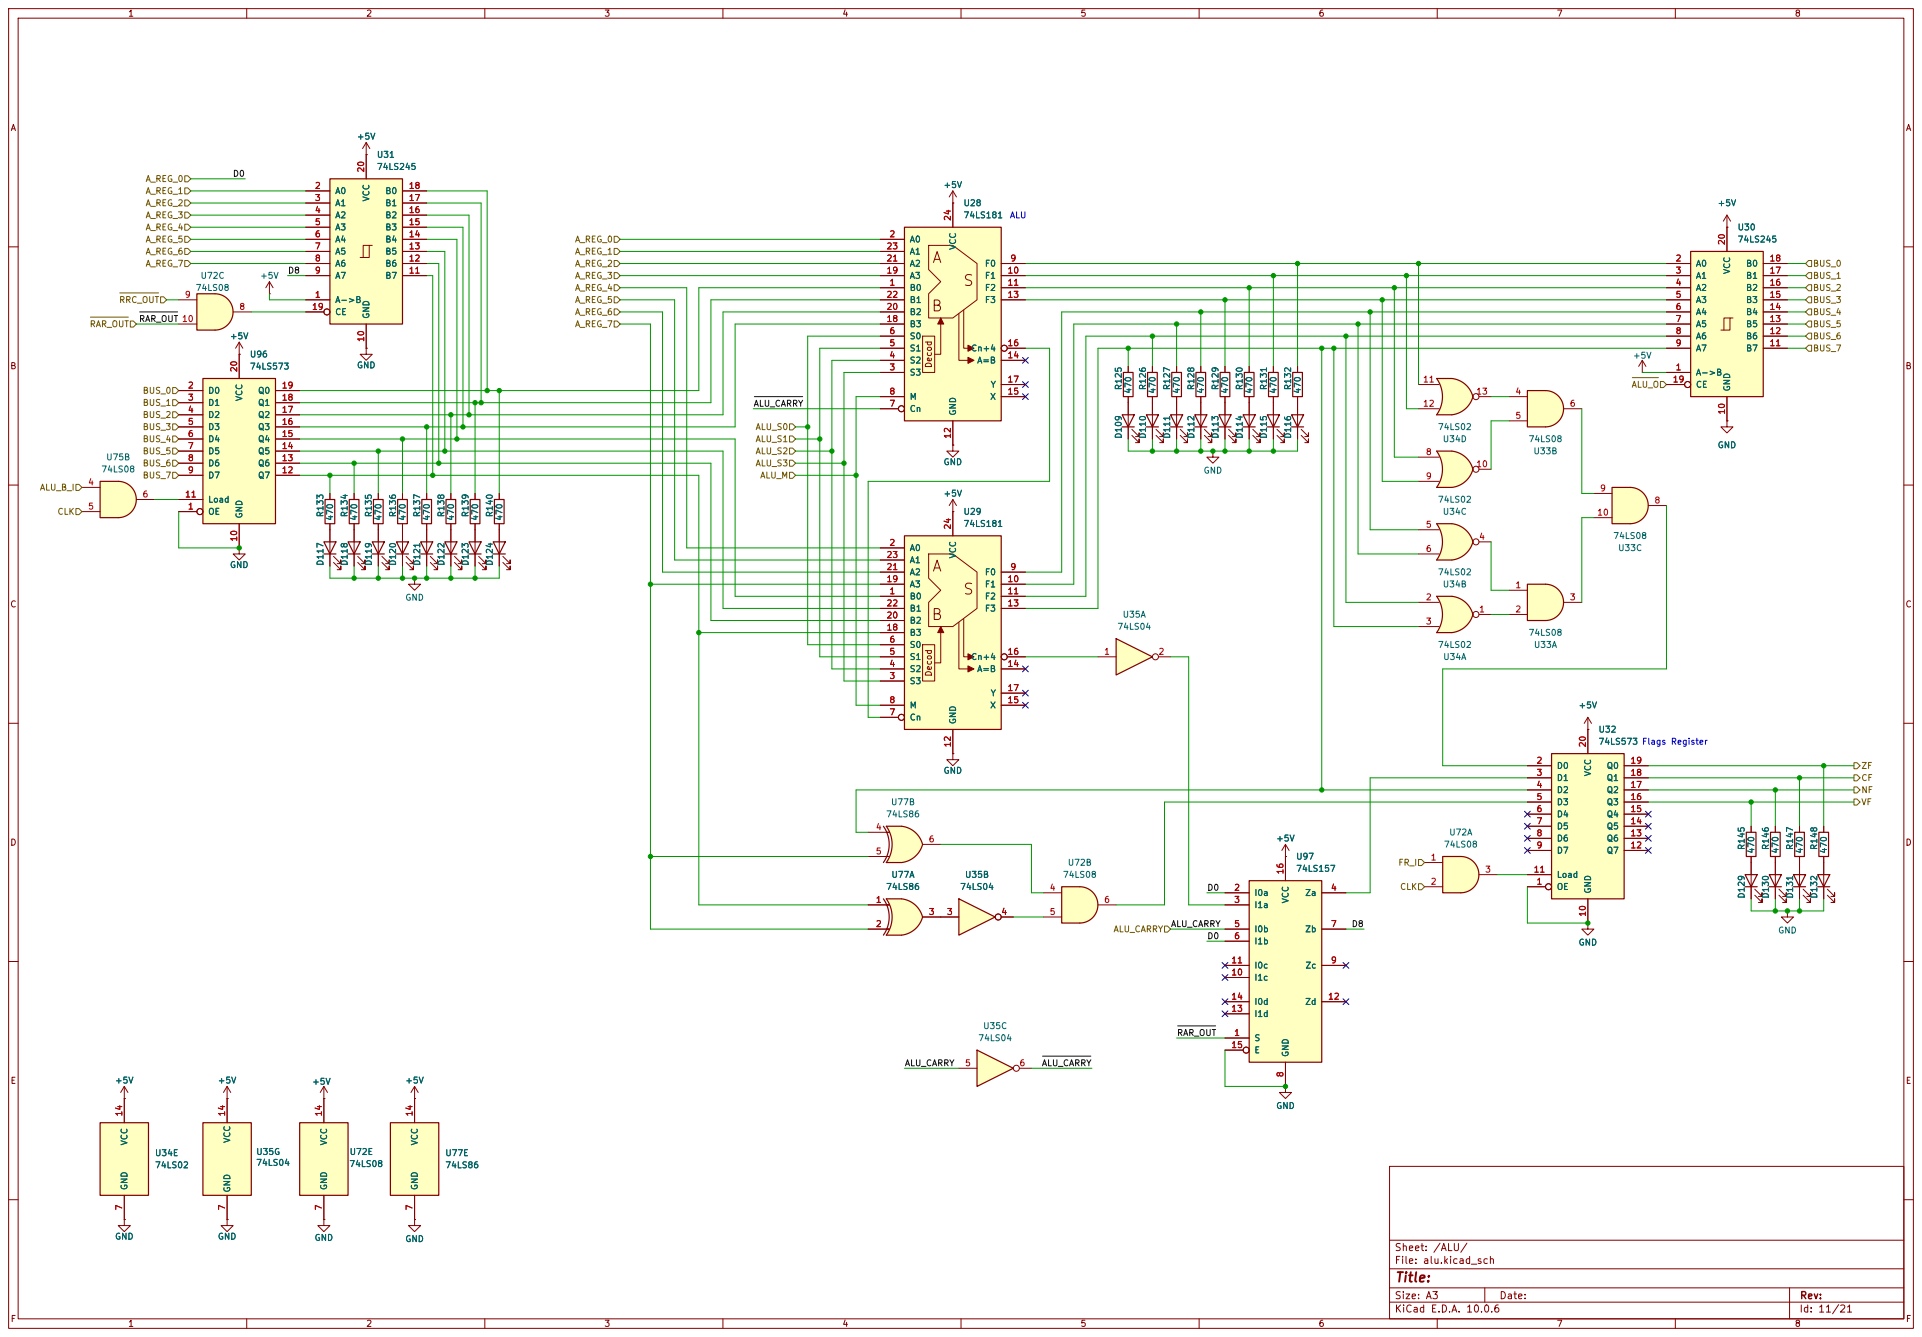
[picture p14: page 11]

VCC 20 U30 | 18 CE 19

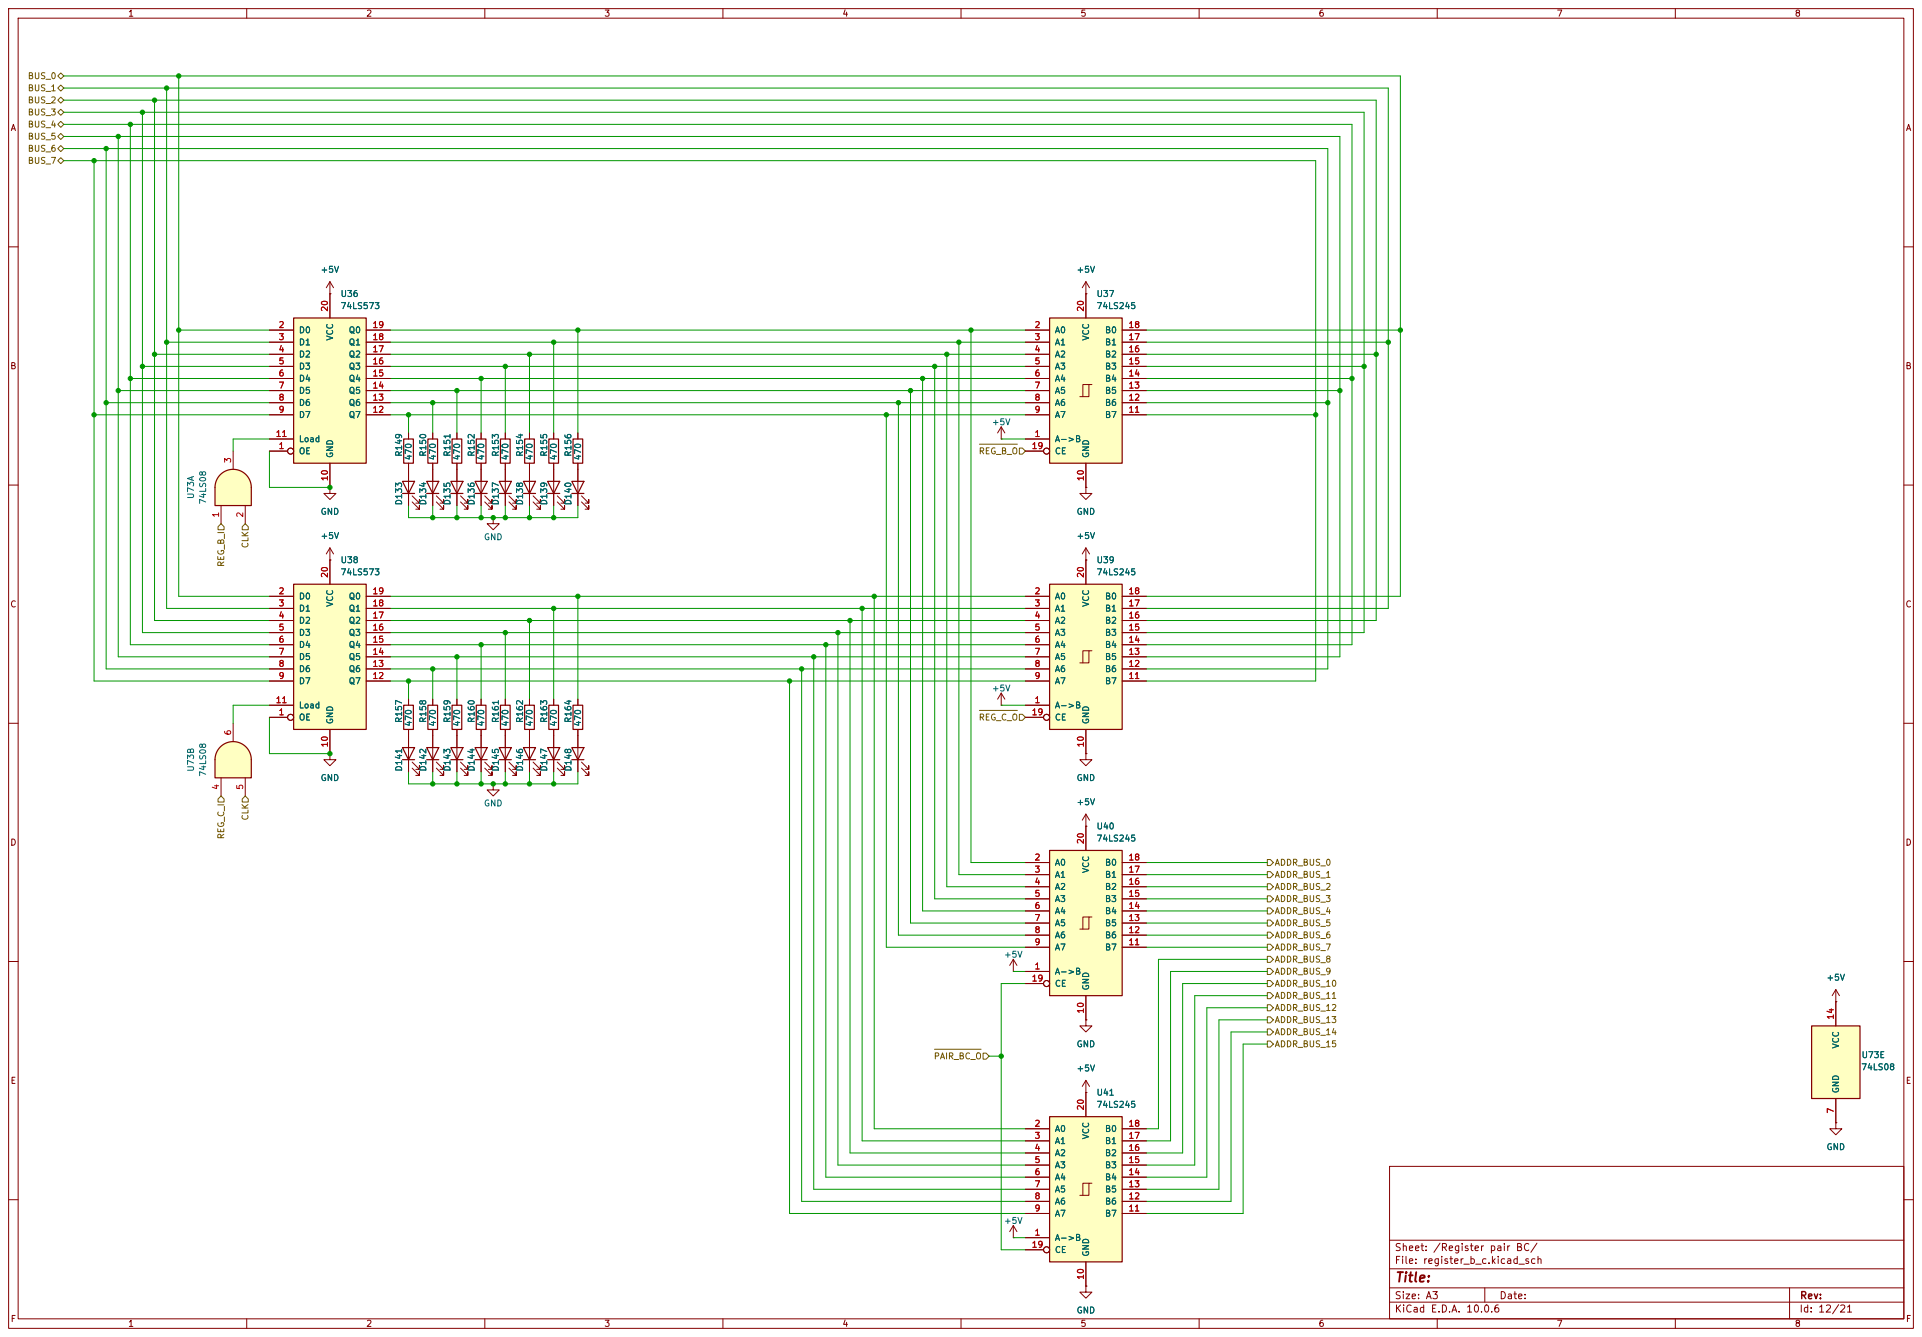
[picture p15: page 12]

A4 6
A5 7
A6 8


A4 6
A5 7
A6 8

Sheet: /Register pair DE/
File: register_d_e.kicad_sch


7 VCC 14 U75E 74LS08 R120 470 D104 R121 470 D105 R123 470 GND R122 470 D103 D107 D108 R124 470 GND GND



reset when RST OR TC OR SC_RST U62A 74LS02

7 VCC 14 +5V GND GND U102E 74LS00 GND


A4 6
A5 5
A6 4
A10 21 OE 22 A10 21 OE 22 A13 26 A13 26
A11 23
A12 2




A2 4
A3 5
A4 6


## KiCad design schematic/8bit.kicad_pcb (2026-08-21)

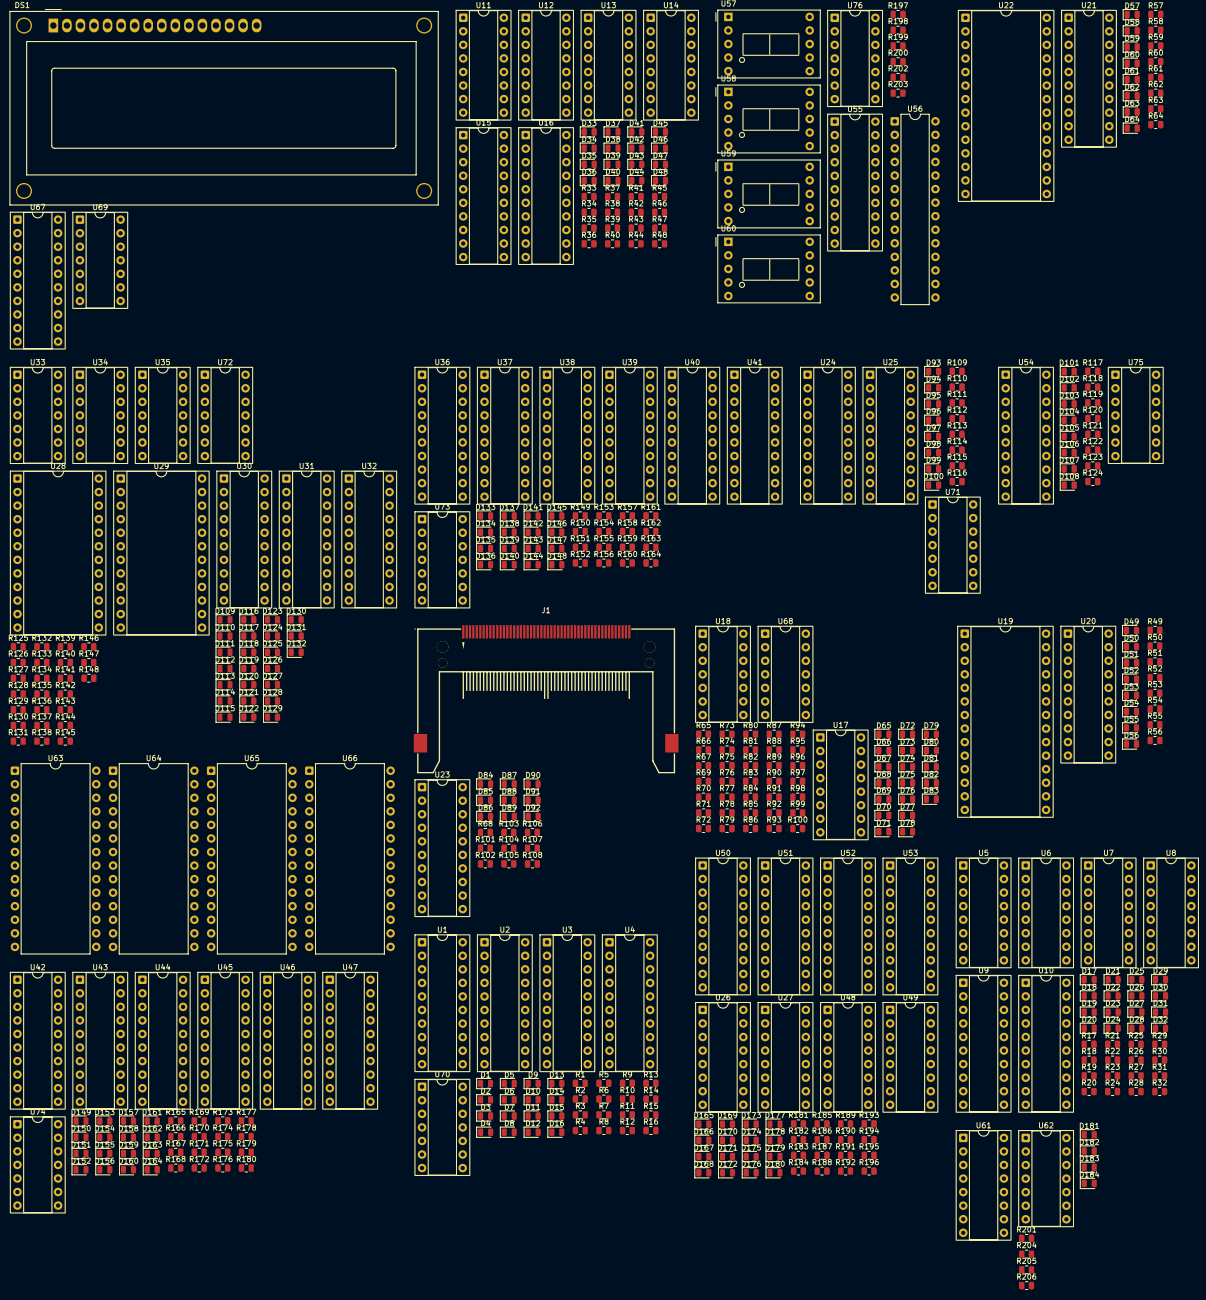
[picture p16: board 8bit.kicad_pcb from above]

Board: 2 copper layers, 468 parts (0 on the bottom side), 560 nets, no tracks yet.

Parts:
D1, D2, D3, D4, D5, D6, D7, D8, D9, D10, D11, D12, D13, D14, D15, D16, D17, D18, D19, D20, D21, D22, D23, D24, D25, D26, D27, D28, D29, D30, D31, D32, D33, D34, D35, D36, D37, D38, D39, D40, D41, D42, D43, D44, D45, D46, D47, D48, D49, D50, D51, D52, D53, D54, D55, D56, D57, D58, D59, D60, D61, D62, D63, D64, D65, D66, D67, D68, D69, D70, D71, D72, D73, D74, D75, D76, D77, D78, D79, D80, D81, D82, D83, D84, D85, D86, D87, D88, D89, D90, D91, D92, D93, D94, D95, D96, D97, D98, D99, D100, D101, D102, D103, D104, D105, D106, D107, D108, D109, D110, D111, D112, D113, D114, D115, D116, D117, D118, D119, D120, D121, D122, D123, D124, D125, D126, D127, D128, D129, D130, D131, D132, D133, D134, D135, D136, D137, D138, D139, D140, D141, D142, D143, D144, D145, D146, D147, D148, D149, D150, D151, D152, D153, D154, D155, D156, D157, D158, D159, D160, D161, D162, D163, D164, D165, D166, D167, D168, D169, D170, D171, D172, D173, D174, D175, D176, D177, D178, D179, D180, D181, D182, D183, D184: LED; LED_0805_2012Metric
DS1: WC1602A
J1: CF; CONN-SMD_HYCW01-CF50-395B
R1, R2, R3, R4, R5, R6, R7, R8, R9, R10, R11, R12, R13, R14, R15, R16, R17, R18, R19, R20, R21, R22, R23, R24, R25, R26, R27, R28, R29, R30, R31, R32, R33, R34, R35, R36, R37, R38, R39, R40, R41, R42, R43, R44, R45, R46, R47, R48, R49, R50, R51, R52, R53, R54, R55, R56, R57, R58, R59, R60, R61, R62, R63, R64, R65, R66, R67, R68, R70, R72, R74, R76, R78, R80, R82, R84, R86, R88, R90, R92, R94, R96, R98, R100, R101, R102, R103, R104, R105, R106, R107, R108, R109, R110, R111, R112, R113, R114, R115, R116, R117, R118, R119, R120, R121, R122, R123, R124, R125, R126, R127, R128, R129, R130, R131, R132, R133, R134, R135, R136, R137, R138, R139, R140, R141, R142, R143, R144, R145, R146, R147, R148, R149, R150, R151, R152, R153, R154, R155, R156, R157, R158, R159, R160, R161, R162, R163, R164, R165, R166, R167, R168, R169, R170, R171, R172, R173, R174, R175, R176, R177, R178, R179, R180, R181, R182, R183, R184, R185, R186, R187, R188, R189, R190, R191, R192, R193, R194, R195, R196, R201, R204, R205, R206: 470; R_0805_2012Metric
R69, R71, R73, R75, R77, R79, R81, R83, R85, R87, R89, R91, R93, R95, R97, R99: 1k; R_0805_2012Metric
R197, R198, R199, R200, R202: 0; R_0805_2012Metric
R203: 4.7k; R_0805_2012Metric
U1, U2, U24, U32, U36, U38, U42, U43, U54, U55, U67: 74LS573; DIP-20_W7.62mm_Socket
U3, U4, U9, U10, U15, U16, U20, U21, U23, U25, U30, U37, U39, U40, U41, U44, U45, U46, U47, U50, U51, U52, U53: 74LS245; DIP-20_W7.62mm_Socket
U5, U6, U7, U8, U61: 74LS161; DIP-16_W7.62mm_Socket
U11, U12, U13, U14, U26, U27, U48, U49: 74LS193; DIP-16_W7.62mm_Socket
U17: 74LS138; DIP-16_W7.62mm_Socket
U18: 74LS20; DIP-14_W7.62mm_Socket
U19: HM62256BLP; DIP-28_W15.24mm_Socket
U22: KM28C64A; DIP-28_W15.24mm_Socket
U28, U29: 74LS181; DIP-24_W15.24mm_Socket
U31: 74LS373; DIP-20_W7.62mm_Socket
U33, U69, U70, U71, U72, U73, U74, U75, U76: 74LS08; DIP-14_W7.62mm_Socket
U34, U62: 74LS02; DIP-14_W7.62mm_Socket
U35: 74LS04; DIP-14_W7.62mm_Socket
U56: ATmega328-P; DIP-28_W7.62mm
U57, U58, U59, U60: D198K; D1X8K
U63, U64, U65, U66: 27C512; DIP-28_W15.24mm
U68: 74LS00; DIP-14_W7.62mm_Socket

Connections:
+5V: DS1.2 (VDD), DS1.15 (LED(+)), J1.13 (VCC), J1.32 (~CS1), J1.36 (~WE), J1.38 (VCC), R65.1, R66.1, R67.1, R203.1, U1.20 (VCC), U2.20 (VCC), U3.1 (A->B), U3.20 (VCC), U4.1 (A->B), U4.20 (VCC), U5.10 (CET), U5.16 (VCC), U6.16 (VCC), U7.16 (VCC), U8.16 (VCC), U9.1 (A->B), U9.20 (VCC), U10.1 (A->B), U10.20 (VCC), U11.16 (VCC), U12.16 (VCC), U13.16 (VCC), U14.16 (VCC), U15.1 (A->B), U15.20 (VCC), U16.1 (A->B), U16.20 (VCC), U17.6 (E3), U17.16 (VCC), U18.14 (VCC), U19.28 (VCC), U20.20 (VCC), U21.1 (A->B), U21.20 (VCC), U22.27 (~WE), U22.28 (VCC), U23.20 (VCC), U24.20 (VCC), U25.1 (A->B), U25.20 (VCC), U26.16 (VCC), U27.16 (VCC), U28.7 (Cn), U28.24 (VCC), U29.24 (VCC), U30.1 (A->B), U30.20 (VCC), U31.20 (VCC), U32.20 (VCC), U34.14 (VCC), U35.14 (VCC), U36.20 (VCC), U37.1 (A->B), U37.20 (VCC), U38.20 (VCC), U39.1 (A->B), U39.20 (VCC), U40.1 (A->B), U40.20 (VCC), U41.1 (A->B), U41.20 (VCC), U42.20 (VCC), U43.20 (VCC), U44.1 (A->B), U44.20 (VCC), U45.1 (A->B), U45.20 (VCC), U46.1 (A->B), U46.20 (VCC), U47.1 (A->B), U47.20 (VCC), U48.16 (VCC), U49.16 (VCC), U50.1 (A->B), U50.20 (VCC), U51.1 (A->B), U51.20 (VCC), U52.1 (A->B), U52.20 (VCC), U53.1 (A->B), U53.20 (VCC), U54.20 (VCC), U55.20 (VCC), U56.7 (VCC), U56.20 (AVCC), U61.7 (CEP), U61.9 (~PE), U61.10 (CET), U61.16 (VCC), U62.14 (VCC), U63.28 (VCC), U64.28 (VCC), U65.28 (VCC), U66.28 (VCC), U67.20 (VCC), U68.14 (VCC), U69.14 (VCC), U70.14 (VCC), U71.14 (VCC), U72.14 (VCC), U73.14 (VCC), U74.14 (VCC), U75.14 (VCC), U76.14 (VCC)
/ALU/ALU_M: U28.8 (M), U29.8 (M)
/ALU/ALU_S0: U28.6 (S0), U29.6 (S0)
/ALU/ALU_S1: U28.5 (S1), U29.5 (S1)
/ALU/ALU_S2: U28.4 (S2), U29.4 (S2)
/ALU/ALU_S3: U28.3 (S3), U29.3 (S3)
/ALU/BUS_0: U30.18 (B0), U31.3 (D0)
/ALU/BUS_1: U30.17 (B1), U31.4 (D1)
/ALU/BUS_2: U30.16 (B2), U31.7 (D2)
/ALU/BUS_3: U30.15 (B3), U31.8 (D3)
/ALU/BUS_4: U30.14 (B4), U31.13 (D4)
/ALU/BUS_5: U30.13 (B5), U31.14 (D5)
/ALU/BUS_6: U30.12 (B6), U31.17 (D6)
/ALU/BUS_7: U30.11 (B7), U31.18 (D7)
/ALU/CF: R147.1, U32.18 (Q1)
/ALU/CLK: U72.2, U72.5
/ALU/EF: R146.1, U32.17 (Q2)
/ALU/ZF: R148.1, U32.19 (Q0)
/Address Decoder/ADDR_BUS_0: R99.1, R100.1
/Address Decoder/ADDR_BUS_1: R97.1, R98.1
/Address Decoder/ADDR_BUS_2: R95.1, R96.1
/Address Decoder/ADDR_BUS_3: R93.1, R94.1
/Address Decoder/ADDR_BUS_4: R91.1, R92.1
/Address Decoder/ADDR_BUS_5: R89.1, R90.1
/Address Decoder/ADDR_BUS_6: R87.1, R88.1
/Address Decoder/ADDR_BUS_7: R85.1, R86.1
/Address Decoder/ADDR_BUS_8: R83.1, R84.1
/Address Decoder/ADDR_BUS_9: R81.1, R82.1
/Address Decoder/ADDR_BUS_10: R79.1, R80.1
/Address Decoder/ADDR_BUS_11: R77.1, R78.1
/Address Decoder/ADDR_BUS_12: R75.1, R76.1, U18.1
/Address Decoder/ADDR_BUS_13: R73.1, R74.1, U17.1 (A0), U18.2
/Address Decoder/ADDR_BUS_14: R71.1, R72.1, U17.2 (A1), U18.4
/Address Decoder/ADDR_BUS_15: D66.1 (K), R69.1, R70.1, U17.3 (A2), U18.5
/Address Decoder/~CF_CS: D67.1 (K), U17.11 (O4)
/Address Decoder/~RAM_I: U68.1, U68.2
/Address Decoder/~ROM_CS: D65.1 (K), U18.6
/CF reader/~CF_CS: J1.7 (~CS0), U23.19 (CE)
/CF reader/~CF_WR: J1.35 (~IOWR), U23.1 (A->B)
/Instruction Decoder/BUS_0: U63.10 (A0), U64.10 (A0), U65.10 (A0), U66.10 (A0)
/Instruction Decoder/BUS_1: U63.9 (A1), U64.9 (A1), U65.9 (A1), U66.9 (A1)
/Instruction Decoder/BUS_2: U63.8 (A2), U64.8 (A2), U65.8 (A2), U66.8 (A2)
/Instruction Decoder/BUS_3: U63.7 (A3), U64.7 (A3), U65.7 (A3), U66.7 (A3)
/Instruction Decoder/BUS_4: U63.6 (A4), U64.6 (A4), U65.6 (A4), U66.6 (A4)
/Instruction Decoder/BUS_5: U63.5 (A5), U64.5 (A5), U65.5 (A5), U66.5 (A5)
/Instruction Decoder/BUS_6: U63.4 (A6), U64.4 (A6), U65.4 (A6), U66.4 (A6)
/Instruction Decoder/BUS_7: U63.3 (A7), U64.3 (A7), U65.3 (A7), U66.3 (A7)
/Instruction Decoder/CF: U63.2 (A12), U64.2 (A12), U65.2 (A12), U66.2 (A12)
/Instruction Decoder/EF: U63.27 (A14), U64.27 (A14), U65.27 (A14), U66.27 (A14)
/Instruction Decoder/STEP_0: U63.25 (A8), U64.25 (A8), U65.25 (A8), U66.25 (A8)
/Instruction Decoder/STEP_1: U63.24 (A9), U64.24 (A9), U65.24 (A9), U66.24 (A9)
/Instruction Decoder/STEP_2: U63.21 (A10), U64.21 (A10), U65.21 (A10), U66.21 (A10)
/Instruction Decoder/STEP_3: U63.23 (A11), U64.23 (A11), U65.23 (A11), U66.23 (A11)
/Instruction Decoder/ZF: U63.26 (A13), U64.26 (A13), U65.26 (A13), U66.26 (A13)
/Instruction Register/IR_0: R124.1, U54.19 (Q0)
/Instruction Register/IR_1: R123.1, U54.18 (Q1)
/Instruction Register/IR_2: R122.1, U54.17 (Q2)
/Instruction Register/IR_3: R121.1, U54.16 (Q3)
/Instruction Register/IR_4: R120.1, U54.15 (Q4)
/Instruction Register/IR_5: R119.1, U54.14 (Q5)
/Instruction Register/IR_6: R118.1, U54.13 (Q6)
/Instruction Register/IR_7: R117.1, U54.12 (Q7)
/MAR/BUS_0: U1.2 (D0), U2.2 (D0)
/MAR/BUS_1: U1.3 (D1), U2.3 (D1)
/MAR/BUS_2: U1.4 (D2), U2.4 (D2)
/MAR/BUS_3: U1.5 (D3), U2.5 (D3)
/MAR/BUS_4: U1.6 (D4), U2.6 (D4)
/MAR/BUS_5: U1.7 (D5), U2.7 (D5)
/MAR/BUS_6: U1.8 (D6), U2.8 (D6)
/MAR/BUS_7: U1.9 (D7), U2.9 (D7)
/MAR/CLK: U70.2, U70.5
/MAR/~MAR_O: U3.19 (CE), U4.19 (CE)
/Program Counter/BUS_0: U5.3 (D0), U7.3 (D0)
/Program Counter/BUS_1: U5.4 (D1), U7.4 (D1)
/Program Counter/BUS_2: U5.5 (D2), U7.5 (D2)
/Program Counter/BUS_3: U5.6 (D3), U7.6 (D3)
/Program Counter/BUS_4: U6.3 (D0), U8.3 (D0)
/Program Counter/BUS_5: U6.4 (D1), U8.4 (D1)
/Program Counter/BUS_6: U6.5 (D2), U8.5 (D2)
/Program Counter/BUS_7: U6.6 (D3), U8.6 (D3)
/Program Counter/CLK: U5.2 (CP), U6.2 (CP), U7.2 (CP), U8.2 (CP)
/Program Counter/PC_E: U5.7 (CEP), U6.7 (CEP), U7.7 (CEP), U8.7 (CEP)
/Program Counter/~JMP_H: U7.9 (~PE), U8.9 (~PE)
/Program Counter/~JMP_L: U5.9 (~PE), U6.9 (~PE)
/Program Counter/~PC_O: U9.19 (CE), U10.19 (CE)
/Program Counter/~RST: U5.1 (~MR), U6.1 (~MR), U7.1 (~MR), U8.1 (~MR)
/RAM/~RAM_CS: U19.20 (~CS), U20.19 (CE)
/RAM/~RAM_I: U19.27 (~WE), U20.1 (A->B)
/ROM/~ROM_CS: U21.19 (CE), U22.20 (~CE)
/Register A/A_REG_0: R116.1, U24.19 (Q0), U25.2 (A0)
/Register A/A_REG_1: R115.1, U24.18 (Q1), U25.3 (A1)
/Register A/A_REG_2: R114.1, U24.17 (Q2), U25.4 (A2)
/Register A/A_REG_3: R113.1, U24.16 (Q3), U25.5 (A3)
/Register A/A_REG_4: R112.1, U24.15 (Q4), U25.6 (A4)
/Register A/A_REG_5: R111.1, U24.14 (Q5), U25.7 (A5)
/Register A/A_REG_6: R110.1, U24.13 (Q6), U25.8 (A6)
/Register A/A_REG_7: R109.1, U24.12 (Q7), U25.9 (A7)
/Register A/BUS_0: U24.2 (D0), U25.18 (B0)
/Register A/BUS_1: U24.3 (D1), U25.17 (B1)
/Register A/BUS_2: U24.4 (D2), U25.16 (B2)
/Register A/BUS_3: U24.5 (D3), U25.15 (B3)
/Register A/BUS_4: U24.6 (D4), U25.14 (B4)
/Register A/BUS_5: U24.7 (D5), U25.13 (B5)
/Register A/BUS_6: U24.8 (D6), U25.12 (B6)
/Register A/BUS_7: U24.9 (D7), U25.11 (B7)
/Register pair BC/BUS_0: U36.2 (D0), U37.18 (B0), U38.2 (D0), U39.18 (B0)
/Register pair BC/BUS_1: U36.3 (D1), U37.17 (B1), U38.3 (D1), U39.17 (B1)
/Register pair BC/BUS_2: U36.4 (D2), U37.16 (B2), U38.4 (D2), U39.16 (B2)
/Register pair BC/BUS_3: U36.5 (D3), U37.15 (B3), U38.5 (D3), U39.15 (B3)
/Register pair BC/BUS_4: U36.6 (D4), U37.14 (B4), U38.6 (D4), U39.14 (B4)
/Register pair BC/BUS_5: U36.7 (D5), U37.13 (B5), U38.7 (D5), U39.13 (B5)
/Register pair BC/BUS_6: U36.8 (D6), U37.12 (B6), U38.8 (D6), U39.12 (B6)
/Register pair BC/BUS_7: U36.9 (D7), U37.11 (B7), U38.9 (D7), U39.11 (B7)
/Register pair BC/CLK: U73.2, U73.5
/Register pair BC/~PAIR_BC_O: U40.19 (CE), U41.19 (CE)
/Register pair DE/BUS_0: U42.2 (D0), U43.2 (D0), U44.18 (B0), U45.18 (B0)
/Register pair DE/BUS_1: U42.3 (D1), U43.3 (D1), U44.17 (B1), U45.17 (B1)
/Register pair DE/BUS_2: U42.4 (D2), U43.4 (D2), U44.16 (B2), U45.16 (B2)
/Register pair DE/BUS_3: U42.5 (D3), U43.5 (D3), U44.15 (B3), U45.15 (B3)
/Register pair DE/BUS_4: U42.6 (D4), U43.6 (D4), U44.14 (B4), U45.14 (B4)
/Register pair DE/BUS_5: U42.7 (D5), U43.7 (D5), U44.13 (B5), U45.13 (B5)
/Register pair DE/BUS_6: U42.8 (D6), U43.8 (D6), U44.12 (B6), U45.12 (B6)
/Register pair DE/BUS_7: U42.9 (D7), U43.9 (D7), U44.11 (B7), U45.11 (B7)
/Register pair DE/CLK: U74.2, U74.5
/Register pair DE/~PAIR_DE_O: U46.19 (CE), U47.19 (CE)
/Register pair HL/BUS_0: U26.15 (A), U48.15 (A), U52.18 (B0), U53.18 (B0)
/Register pair HL/BUS_1: U26.1 (B), U48.1 (B), U52.17 (B1), U53.17 (B1)
/Register pair HL/BUS_2: U26.10 (C), U48.10 (C), U52.16 (B2), U53.16 (B2)
/Register pair HL/BUS_3: U26.9 (D), U48.9 (D), U52.15 (B3), U53.15 (B3)
/Register pair HL/BUS_4: U27.15 (A), U49.15 (A), U52.14 (B4), U53.14 (B4)
/Register pair HL/BUS_5: U27.1 (B), U49.1 (B), U52.13 (B5), U53.13 (B5)
/Register pair HL/BUS_6: U27.10 (C), U49.10 (C), U52.12 (B6), U53.12 (B6)
/Register pair HL/BUS_7: U27.9 (D), U49.9 (D), U52.11 (B7), U53.11 (B7)
/Register pair HL/RST: U26.14 (CLR), U27.14 (CLR), U48.14 (CLR), U49.14 (CLR)
/Register pair HL/~PAIR_HL_O: U50.19 (CE), U51.19 (CE)
/Register pair HL/~REG_H_I: U48.11 (~LOAD), U49.11 (~LOAD)
/Register pair HL/~REG_L_I: U26.11 (~LOAD), U27.11 (~LOAD)
/Stack Pointer/BUS_0: U11.15 (A), U13.15 (A)
/Stack Pointer/BUS_1: U11.1 (B), U13.1 (B)
/Stack Pointer/BUS_2: U11.10 (C), U13.10 (C)
/Stack Pointer/BUS_3: U11.9 (D), U13.9 (D)
/Stack Pointer/BUS_4: U12.15 (A), U14.15 (A)
/Stack Pointer/BUS_5: U12.1 (B), U14.1 (B)
/Stack Pointer/BUS_6: U12.10 (C), U14.10 (C)
/Stack Pointer/BUS_7: U12.9 (D), U14.9 (D)
/Stack Pointer/RST: U11.14 (CLR), U12.14 (CLR), U13.14 (CLR), U14.14 (CLR)
/Stack Pointer/~SP_H_I: U13.11 (~LOAD), U14.11 (~LOAD)
/Stack Pointer/~SP_L_I: U11.11 (~LOAD), U12.11 (~LOAD)
/Stack Pointer/~SP_O: U15.19 (CE), U16.19 (CE)
/Step Counter/STEP_0: R206.1, U61.14 (Q0)
/Step Counter/STEP_1: R205.1, U61.13 (Q1)
/Step Counter/STEP_2: R204.1, U61.12 (Q2)
/Step Counter/STEP_3: R201.1, U61.11 (Q3)
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

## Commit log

2026-08-20 chore: sync files
    [8bit.kicad_pcb, 8bit.kicad_sch, address_decoder.kicad_sch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]
2026-08-24 chore: add files for simulation
    [alu.kicad_sch, register_h_l.kicad_sch]
2026-09-27 chore: sync design between simulation and schematic
    [8bit.csv, 8bit.kicad_sch, alu.kicad_sch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]
2026-10-04 chore: clean root
    [8bit.kicad_pcb, 8bit.kicad_sch, address_decoder.kicad_sch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]
2026-10-04 refactor: remove redundant root schematic files and update README
    [8bit.kicad_pcb, 8bit.kicad_sch, address_decoder.kicad_sch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]
2026-10-05 chore: sync outdated schematic files
    [8bit.kicad_sch, address_decoder.kicad_sch, lcd_driver.kicad_sch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]
2026-10-29 chore: update bom and footprintss
2026-10-31 chore: update bom and add prices
